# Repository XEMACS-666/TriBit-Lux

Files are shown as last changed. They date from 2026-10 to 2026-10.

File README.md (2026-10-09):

# ☀️ TriBit Lux

### From an LDR experiment to a real hardware PCB.

**TriBit Lux** is a 3-bit flash ADC–style brightness indicator that converts ambient light into a digital level and displays it on a seven-segment display.

The interesting part isn't just the final circuit.

It is the **evolution of the circuit**:

> **What started as Arduino-controlled logic gradually became hardware-controlled logic, then a breadboard prototype, and finally a PCB.**

```text
       LIGHT
         ↓
       LDR
         ↓
    Analog Voltage
         ↓
  LM339 Comparators
         ↓
   Comparator Levels
         ↓
     74F148
  Priority Encoder
         ↓
      3-bit Code
         ↓
      74LS48
  Display Decoder
         ↓
    7-Segment
```

---

## 🧭 The Journey

```text
🧪 V0.0
TinkerCAD + Arduino
     ↓
🌤️ V0.1
Real LDR + Comparators
     ↓
🔌 V1.0
First Breadboard
     ↓
🧠 V1.1
Hardware Priority Encoder
     ↓
🔢 V1.2
Hardware 7-Segment Decoder
     ↓
📟 V1.3
LCD Monitoring
     ↓
🟢 V2.0
KiCad PCB
     ↓
🚧 V2.1
Fabricated Hardware
```

Every version was built to answer a different question.

---

# 🧪 V0.0 — Can the idea work?

### TinkerCAD simulation

The first goal wasn't to make a sophisticated ADC.

It was simply to prove the basic idea:

> **Can a changing analog voltage be converted into a small number of brightness levels and represented digitally?**

Since using a real LDR inside the simulation wasn't the starting point, a **potentiometer** was used to imitate the changing sensor voltage.

The Arduino handled the interpretation and seven-segment display control in software.

### Circuit idea

```text
Potentiometer
     │
     ▼
Comparator Bank
     │
     ▼
Arduino
     │
     ▼
7-Segment Display
```

### 🖼️ Simulation

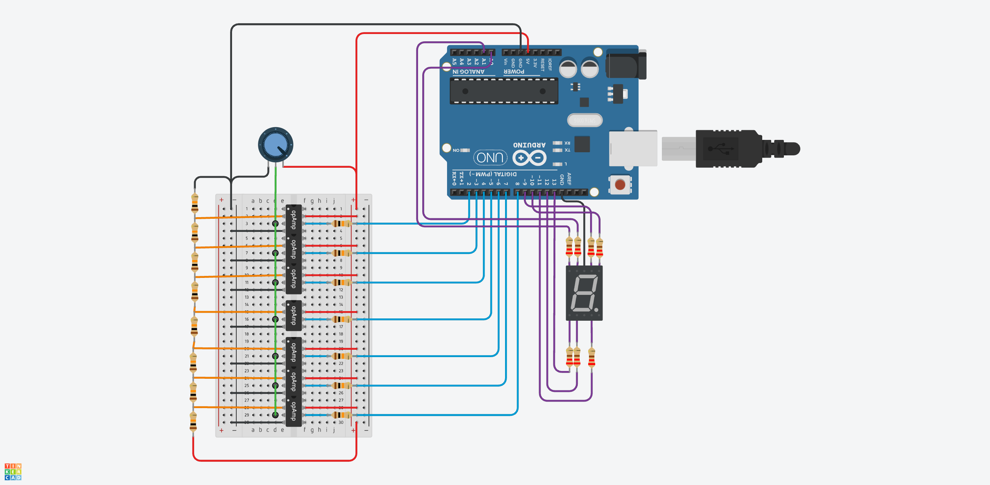
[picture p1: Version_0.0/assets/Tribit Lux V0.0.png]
TriBit Lux V0.0 simulation


**What this version proved:** the overall concept was workable.

**What it didn't prove:** whether the system would behave like a real light sensor.

**So the next question became:**

> What happens when the potentiometer is replaced by actual light?

### 🔗 Files

[TinkerCAD simulation](https://www.tinkercad.com/things/60Tk7pVbgVW-tribit-lux-v00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) · [Schematic](Version_0.0/schematic/Tribit%20Lux%20V0.0.pdf) · [Arduino sketch](Version_0.0/firmware/tribit_lux_v0_00/tribit_lux_v0_00.ino) · [BOM](Version_0.0/bom/bom.csv)

---

# 🌤️ V0.1 — Can real light drive the circuit?

### LDR + LM339

The potentiometer had done its job.

Now it was time to replace the artificial voltage source with the actual thing TriBit Lux was supposed to measure:

**light.**

An **LDR** was introduced together with **LM339 comparators**.

The analog part of the system was now starting to resemble the intended hardware architecture.

```text
            LIGHT
              ↓
             LDR
              ↓
       Voltage Divider
              ↓
       ┌──────────────┐
       │   LM339 × 2  │
       │  Comparators │
       └──────┬───────┘
              ↓
       Digital Levels
              ↓
           Arduino
```

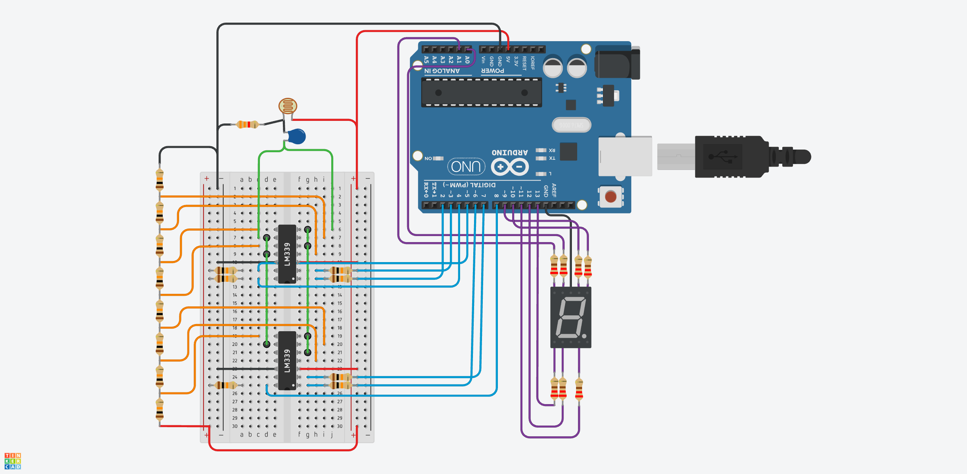
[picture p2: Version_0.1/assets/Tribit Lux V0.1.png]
TriBit Lux V0.1 simulation


The Arduino was still doing the **priority encoding and display logic**, but the important change was that the input was now responding to the real physical quantity of interest.

**Design realization:** the circuit was no longer just a software experiment. The analog front-end itself was becoming real hardware.

### 🔗 Files

[TinkerCAD simulation](https://www.tinkercad.com/things/gNVAR2cQYVG-tribit-lux-v01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) · [Schematic](Version_0.1/schematic/Tribit%20Lux%20V0.1.pdf) · [Arduino sketch](Version_0.1/firmware/tribit_lux_v0_01/tribit_lux_v0_01.ino) · [BOM](Version_0.1/bom/bom.csv)

---

# 🔌 V1.0 — What happens when the simulator becomes a breadboard?

### First physical prototype

At this point, simulation had answered enough questions.

The next step was simple:

> **Build it.**

The LDR and two LM339s were moved onto a physical breadboard, and an **Arduino Nano** was used to read the comparator outputs and control the display.

### ✨ 7-segment pin visualizer

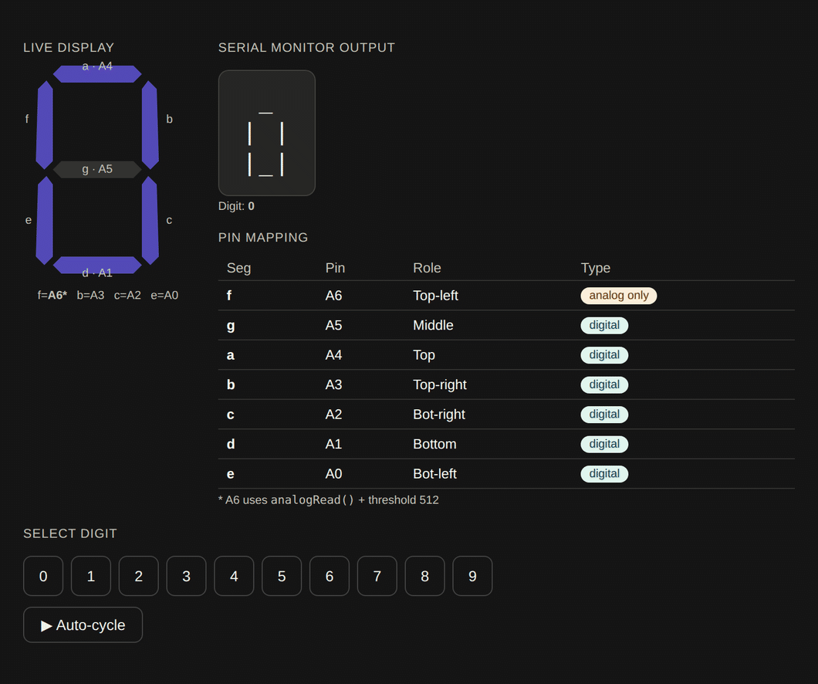
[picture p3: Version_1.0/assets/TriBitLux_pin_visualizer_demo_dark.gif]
Animated TriBit Lux 7-segment pin visualizer


*An animated guide to the seven-segment display pin layout. The breadboard recording is a video, so use the link below to open it.*

The important lesson here was that simulation and physical electronics are not quite the same thing.

Now the project had to deal with:

- actual component tolerances
- real wiring
- power connections
- sensor behaviour
- breadboard parasitics
- physical display pin arrangements

The Arduino still performed most of the digital decision-making.

That raised the next engineering question:

> **Why should a microcontroller perform a job that a digital logic IC can perform directly?**

### 🔗 Files

[▶️ Watch the breadboard video](Version_1.0/assets/TriBitLux_V1_0%202026-10-06%20at%2023.10.18.mp4) · [Open the interactive 7-segment pin visualizer](https://xemacs-666.github.io/TriBit-Lux/Version_1.0/assets/TriBitLux_V1_0_pin_visualizer.html) · [Serial visualizer sketch](Version_1.0/firmware/TriBitLux_V1_0_visualizer/TriBitLux_V1_0_visualizer.ino)

> The visualizer sketch is a learning/debugging aid, not the complete V1.0 firmware.

---

# 🧠 V1.1 — Can the hardware make the decision?

### Introducing the 74F148

This was the first major step toward the original hardware-design idea.

Instead of asking the Arduino:

> "Which comparator is active?"

the circuit now contains a dedicated **74F148 priority encoder**.

```text
LM339 Comparator Bank
         │
         ▼
    Thermometer
       Code
         │
         ▼
      74F148
  Priority Encoder
         │
         ▼
      3-bit
      Output
         │
         ▼
      Arduino
```

### 🖼️ Prototype and layout

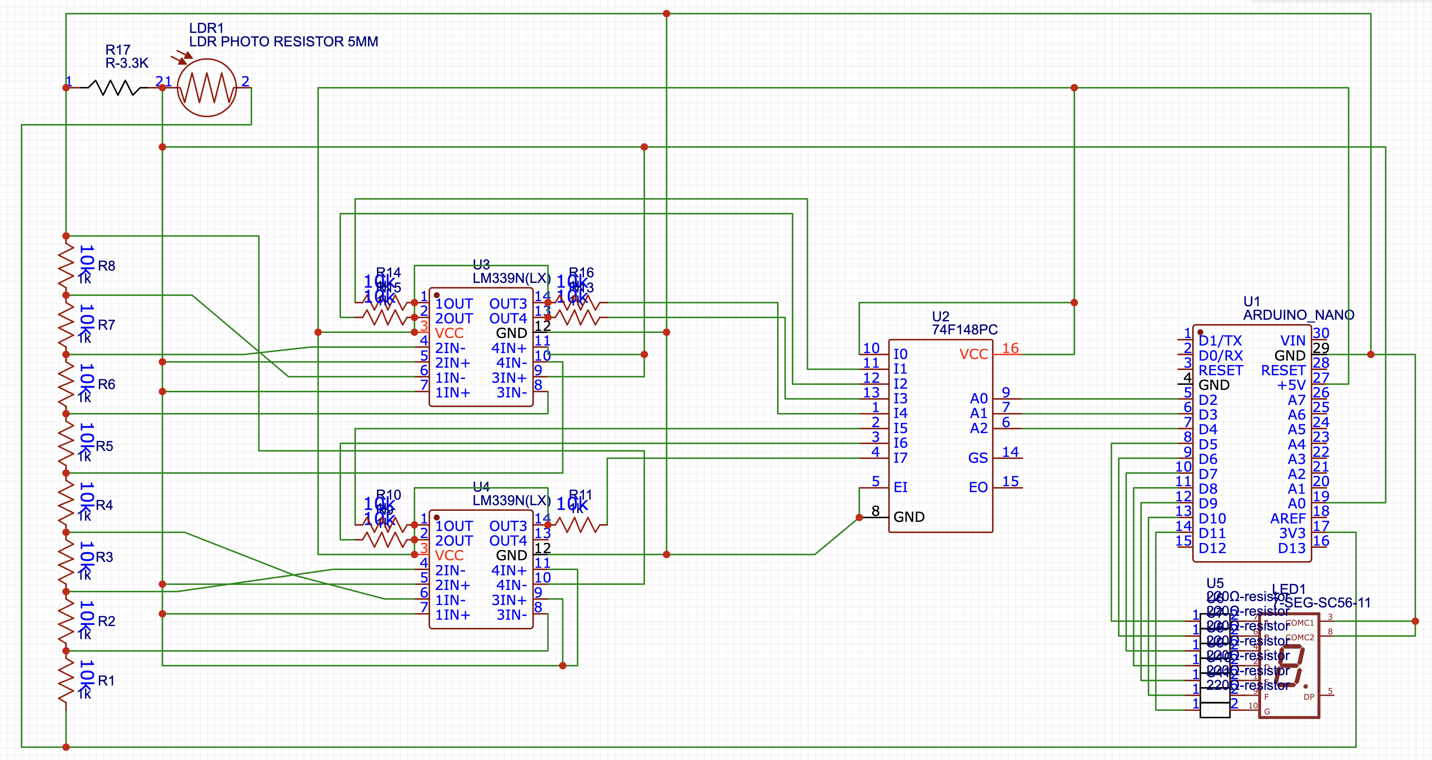
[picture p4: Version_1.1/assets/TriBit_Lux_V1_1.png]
V1.1 schematic


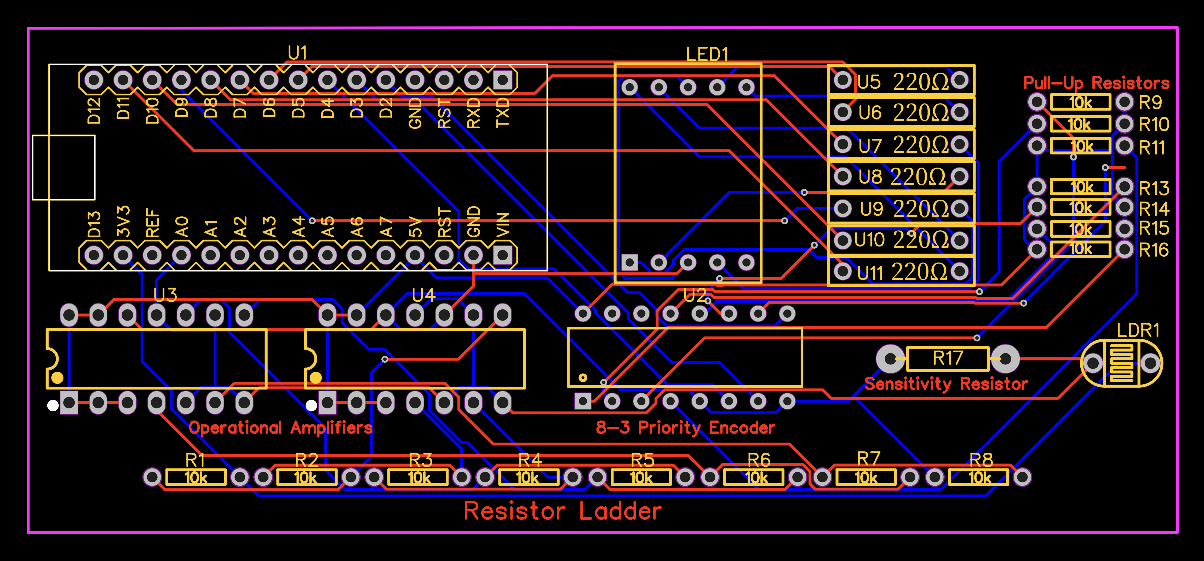
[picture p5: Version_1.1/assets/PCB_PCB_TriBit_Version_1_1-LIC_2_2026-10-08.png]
V1.1 PCB layout


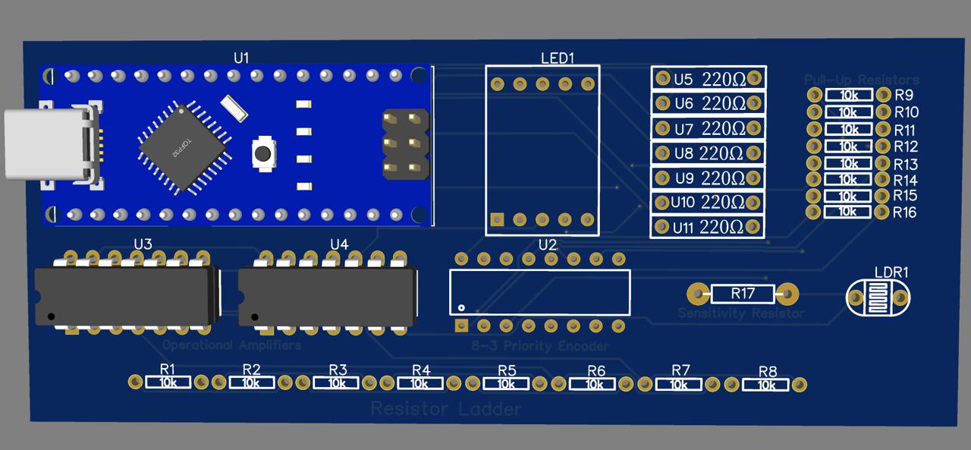
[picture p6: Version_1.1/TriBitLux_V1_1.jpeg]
V1.1 prototype


### Why this mattered

The Arduino wasn't removed.

Instead, its role was deliberately reduced.

The goal was to understand the boundary between **analog hardware, digital logic and software**.

The 74F148 now handled the priority encoding, while the Nano simply observed the result.

This version marked the transition from:

**"Arduino reads the circuit"**

to

**"The circuit itself produces a meaningful digital result."**

### 🔗 Files

[Schematic](Version_1.1/schematic/) · [PCB](Version_1.1/pcb/) · [BOM](Version_1.1/bom/) · [Gerbers](Version_1.1/gerbers/)

---

# 🔢 V1.2 — Can the display become hardware too?

### Introducing the 74LS48

The next dependency on the Arduino was even more obvious.

The encoder already produced a digital code.

So why should the Nano turn that code into seven-segment signals?

It shouldn't.

The **74LS48** was added to perform the display decoding directly in hardware.

```text
LM339
 │
 ▼
74F148
 │
 │ 3-bit code
 ▼
74LS48
 │
 ▼
7-Segment
```

### Physical build

| Prototype view 1 | Prototype view 2 | Prototype view 3 |
|:---:|:---:|:---:|
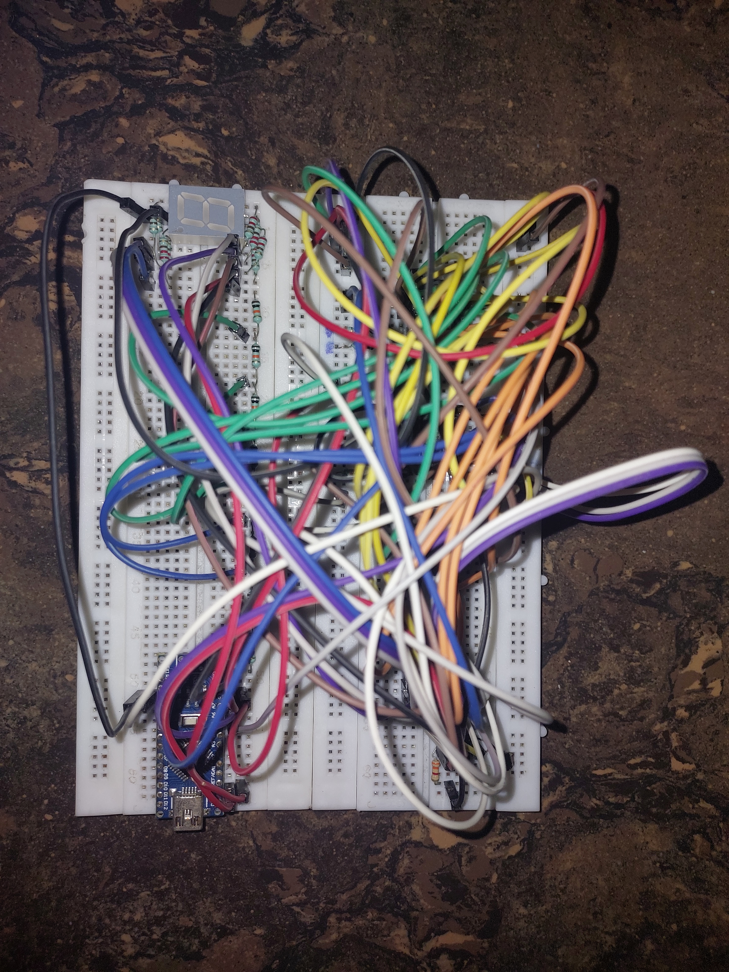
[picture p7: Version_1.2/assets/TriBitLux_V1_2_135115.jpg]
V1.2 prototype view 1
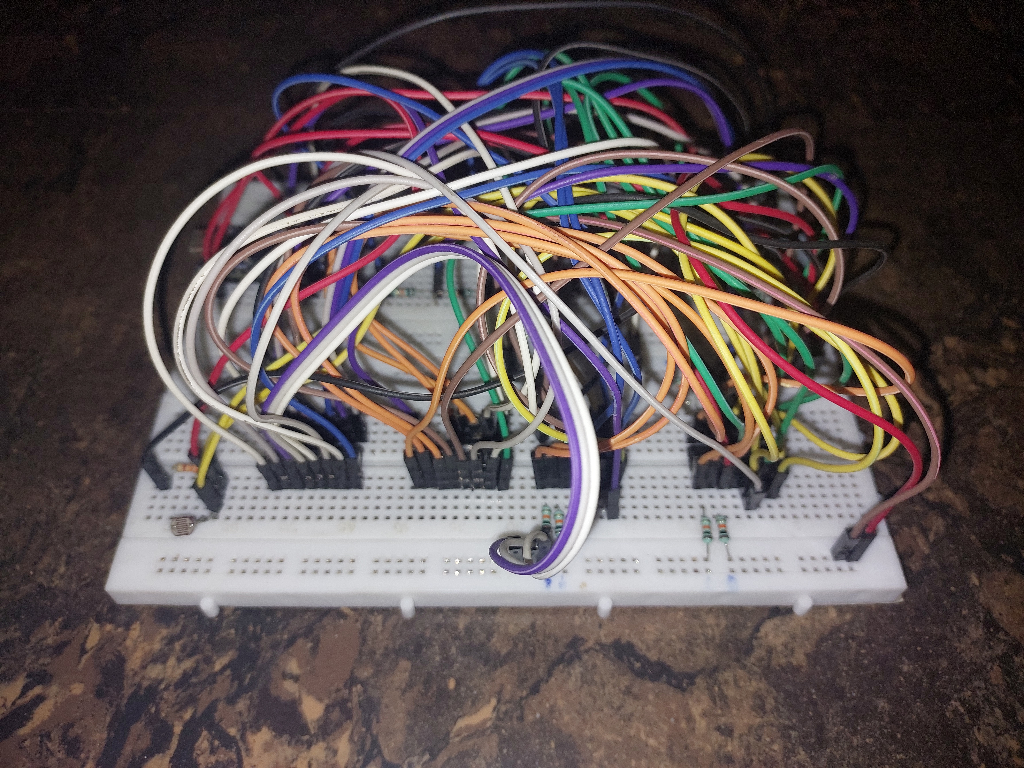
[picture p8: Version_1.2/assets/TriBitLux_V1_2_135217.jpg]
V1.2 prototype view 2
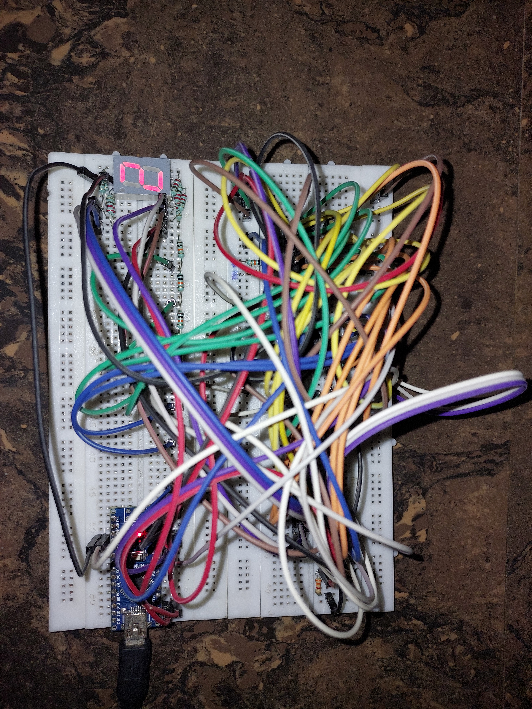
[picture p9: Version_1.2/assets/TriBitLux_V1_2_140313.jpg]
V1.2 prototype view 3
|  |  |  |

Now the complete display path was handled by dedicated hardware.

The Arduino's job became much smaller:

> **Observe the binary output and print it to the serial monitor for verification.**

This was an important milestone because the seven-segment display was now **physically driven by logic ICs rather than Arduino display code**.

### 🔗 Files

[Nano serial-monitor sketch](Version_1.2/firmware/TriBitLux_V1_2_LIC/TriBitLux_V1_2_LIC.ino) · [Video](Version_1.2/assets/)

> The sketch also contains seven-segment output code for experimentation, but that is **not** the display path used in the photographed V1.2 build.

---

# 📟 V1.3 — What if the circuit could tell us more?

### Adding an LCD

The seven-segment display tells us the **level**.

But during development, another question became useful:

> **What is the sensor voltage actually doing?**

So a **16×2 I²C LCD** was added.

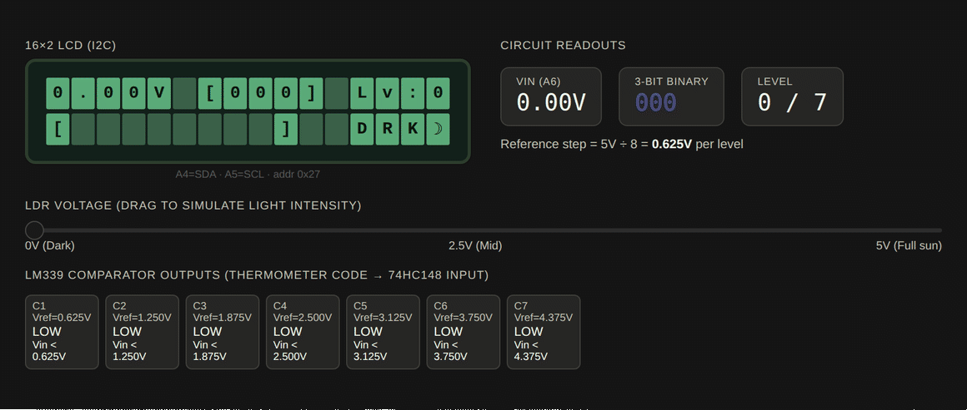
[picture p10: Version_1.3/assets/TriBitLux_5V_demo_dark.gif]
Animated V1.3 light-level demonstration


*Animated 5 V demonstration of the TriBit Lux indicator.*

### 🖼️ Prototype gallery

| Prototype view 1 | Prototype view 2 |
|:---:|:---:|
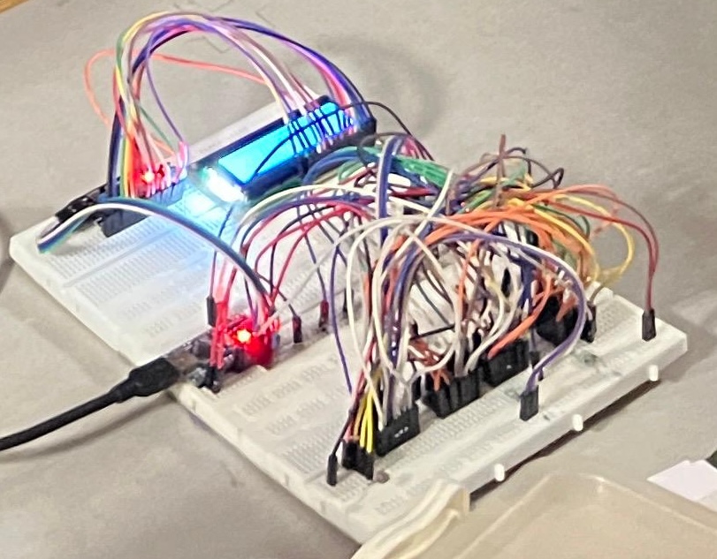
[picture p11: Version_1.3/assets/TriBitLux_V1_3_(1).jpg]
V1.3 prototype with LCD, view 1
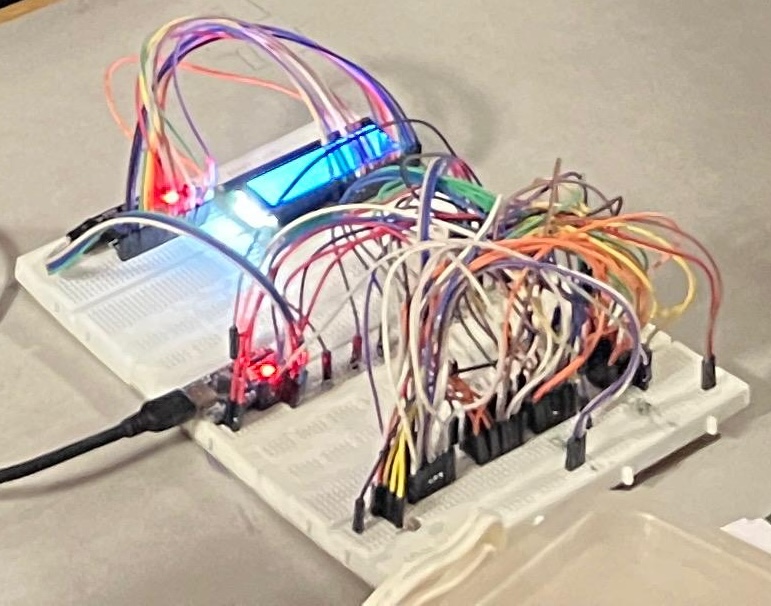
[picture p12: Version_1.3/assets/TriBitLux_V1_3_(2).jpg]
V1.3 prototype with LCD, view 2
|  |  |

This version wasn't intended to replace the hardware logic.

Instead, it became a **development and monitoring stage**.

The Nano reads the LDR voltage through its analog input and calculates the displayed level in software.

```text
            LDR
             │
             ├──────────► LM339 → 74F148 → 74LS48 → 7-Segment
             │
             ▼
         Arduino ADC
             │
             ▼
            LCD
```

This is important because **V1.3's LCD firmware does not read the 74F148 outputs**.

It independently measures the LDR voltage and calculates the level.

That made the LCD useful for understanding what was happening inside the analog section while the hardware seven-segment path continued doing its own job.

### 🔗 Files

[Photo 1](Version_1.3/assets/TriBitLux_V1_3%20%281%29.jpg) · [Photo 2](Version_1.3/assets/TriBitLux_V1_3%20%282%29.jpg) · [Open the 5 V LCD visualization](https://xemacs-666.github.io/TriBit-Lux/Version_1.3/assets/TriBitLux_V1_3_%285V%29.html) · [LCD sketch](Version_1.3/firmware/TriBitLux_V1_3/TriBitLux_V1_3.ino)

---

# 🟢 V2.0 — Can the whole thing become a proper board?

### From jumper wires to copper traces.

By now the architecture had been tested through multiple physical iterations.

The next problem was no longer:

> "Does the circuit work?"

It was:

> **"Can I package the circuit into something compact, repeatable and manufacturable?"**

That became **V2.0**.

The circuit was recreated in **KiCad** as an editable schematic and PCB layout.

### 🖼️ V2.0 design gallery

| Schematic | PCB layout |
|:---:|:---:|
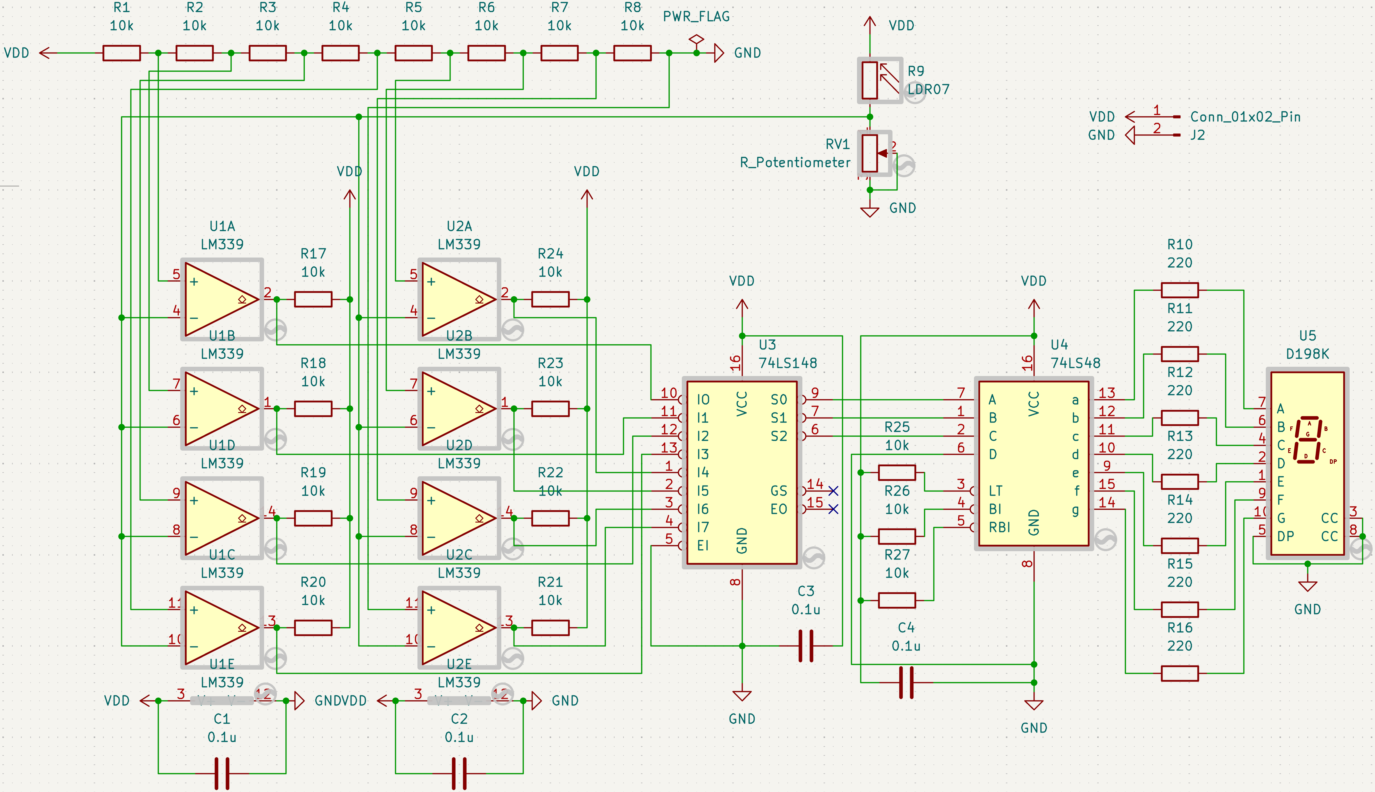
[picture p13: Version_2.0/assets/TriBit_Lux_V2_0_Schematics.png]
V2.0 schematic
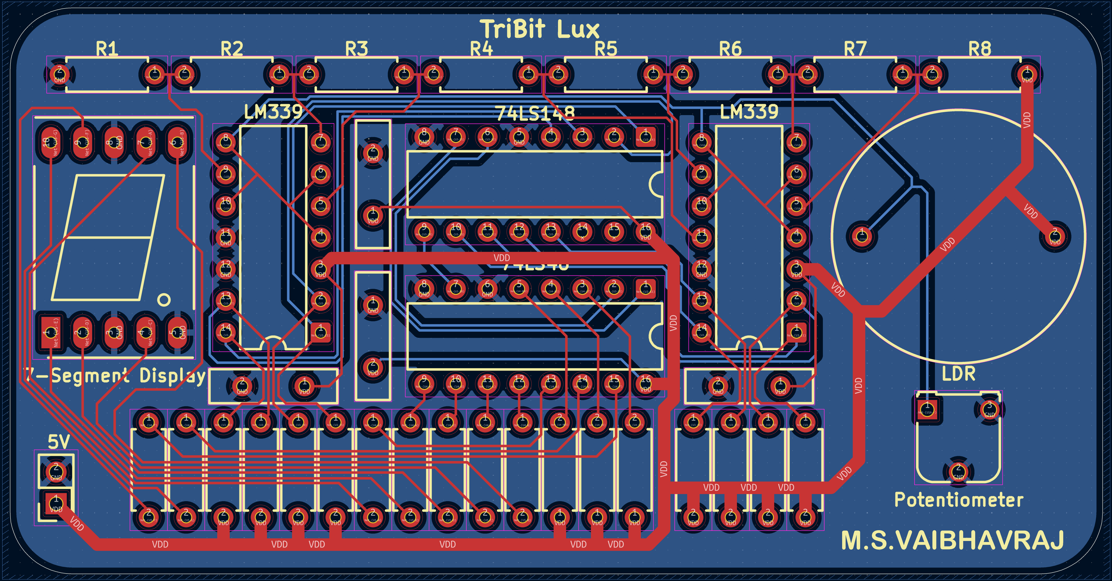
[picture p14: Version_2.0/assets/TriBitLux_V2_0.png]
V2.0 PCB layout
|  |  |

| PCB top view | PCB bottom view |
|:---:|:---:|
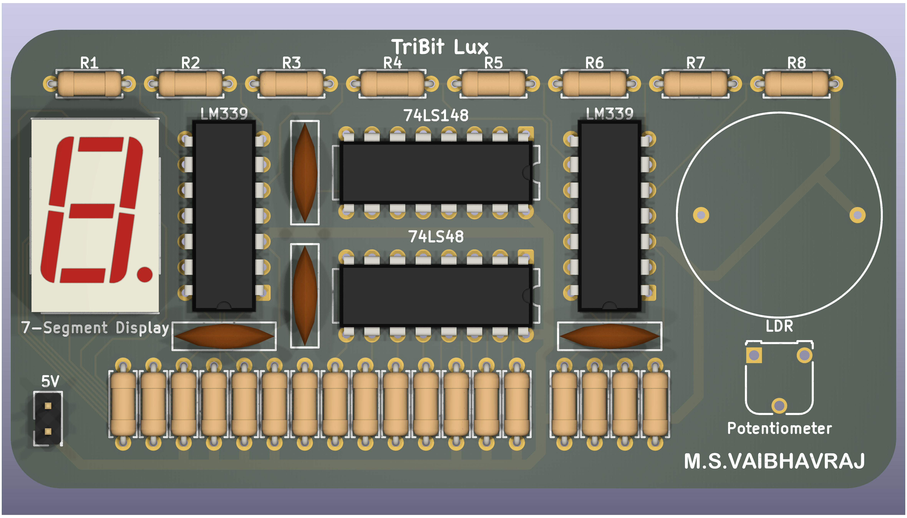
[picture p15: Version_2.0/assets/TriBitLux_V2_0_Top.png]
V2.0 PCB top view
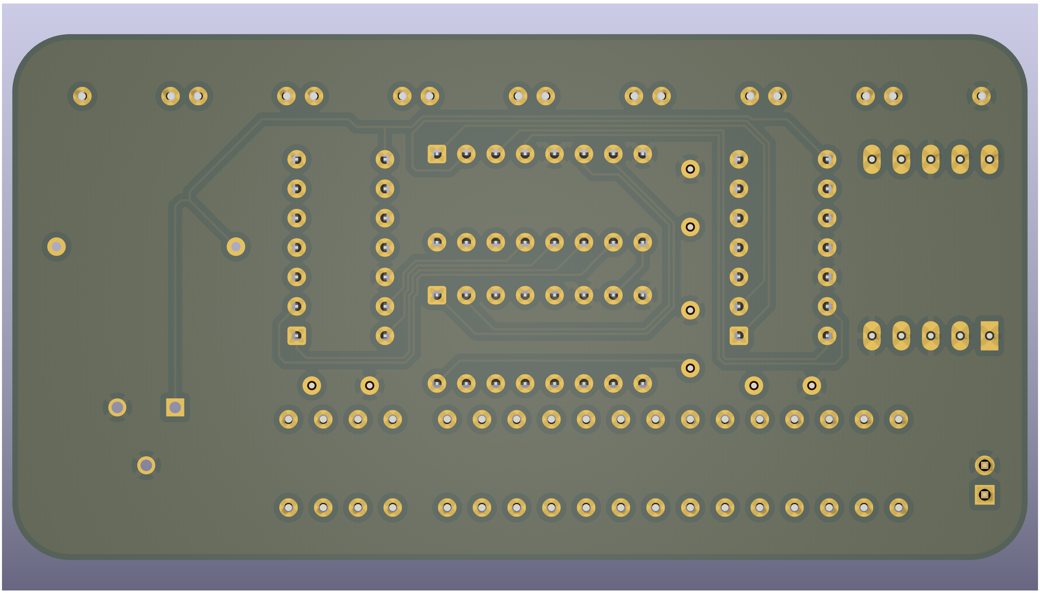
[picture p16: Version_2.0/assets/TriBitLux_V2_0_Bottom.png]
V2.0 PCB bottom view
|  |  |

### What changed?

**☀️ 20 mm LDR opening**

The sensor opening was enlarged to make physical placement and light exposure more practical.

**🎚️ Adjustable sensitivity**

A potentiometer was introduced so the response of the brightness indicator can be adjusted rather than being completely fixed.

**🛡️ 0.1 µF decoupling**

Local bypass capacitors were added around the IC supply rails to improve supply stability and reduce unwanted noise.

**🧱 Through-hole construction**

The board remains intentionally friendly to manual assembly, inspection and modification.

---

# 🧩 V2.0 Hardware Architecture

```text
                      ☀️ LIGHT
                         │
                         ▼
                   ┌───────────┐
                   │    LDR    │
                   └─────┬─────┘
                         │
                   Sensor Voltage
                         │
                         ▼
              ┌────────────────────┐
              │      LM339 × 2     │
              │  Comparator Bank   │
              └─────────┬──────────┘
                        │
                  7 comparator
                    decisions
                        │
                        ▼
                ┌──────────────┐
                │    74F148    │
                │   Priority   │
                │    Encoder   │
                └───────┬──────┘
                        │
                      3 bits
                   ┌────┴────┐
                   ▼         ▼
              Debug/Test   74LS48
                              │
                              ▼
                          7-Segment
                           Display
```

The important architectural change is that the **core signal path no longer depends on the Arduino**.

---

# 🏗️ Inside V2.0

The editable KiCad project is kept here:

```text
Version_2.0/
└── TriBitLux_V2_0/
    ├── TriBitLux_V2_0.kicad_pro
    ├── TriBitLux_V2_0.kicad_sch
    └── TriBitLux_V2_0.kicad_pcb
```

Only the actual KiCad design files are tracked.

KiCad-generated temporary files such as:

```text
fp-info-cache
*.kicad_prl
*.kicad_sch-bak
*-backups/
```

are intentionally excluded from version control.

Manufacturing outputs are kept separately:

```text
Version_2.0/
├── gerber/
│   └── gerber.zip
├── bom/
├── cpl/
├── schematic/
└── TriBitLux_V2_0/
    ├── TriBitLux_V2_0.kicad_pro
    ├── TriBitLux_V2_0.kicad_sch
    └── TriBitLux_V2_0.kicad_pcb
```

### Current status

**PCB design complete. Fabrication pending.**

```text
Schematic
   ✅
    ↓
PCB Layout
   ✅
    ↓
Gerber Generation
   ✅
    ↓
Manufacturing
   ⏳
    ↓
Assembly
   ⏳
    ↓
Power-up
   ⏳
    ↓
Real-world validation
   ⏳
```

---

# 📈 The Engineering Progression

The versions are not just revisions of the same circuit.

Each one removed uncertainty.

| Version | Question being answered |
|:---:|---|
| **V0.0** | Can the basic concept work? |
| **V0.1** | Can actual light be converted into useful comparator states? |
| **V1.0** | Does the circuit survive physical implementation? |
| **V1.1** | Can priority encoding be moved into hardware? |
| **V1.2** | Can display decoding also be moved into hardware? |
| **V1.3** | Can additional measurements help understand the circuit? |
| **V2.0** | Can the validated circuit be packaged into a PCB? |
| **V2.1** | Will the manufactured PCB actually work? |

---

# 🚧 V2.1 — The Board Meets Reality

The next version won't begin in KiCad.

It will begin with a box containing a fabricated PCB.

### Planned validation

```text
PCB Arrival
   ↓
Visual Inspection
   ↓
Continuity Check
   ↓
5 V Rail Check
   ↓
IC Power Verification
   ↓
Comparator Threshold Test
   ↓
74F148 Verification
   ↓
74LS48 + Display Test
   ↓
LDR Response
   ↓
Sensitivity Adjustment
   ↓
Full Brightness Test
```

The first successful power-up will be a different kind of milestone from everything before it.

Until then:

> **V2.0 is a design.  
> V2.1 will prove whether the design was right.**

---

# 📂 Repository Structure

```text
TriBit Lux/
│
├── README.md
├── .gitignore
│
├── Version_0.0/
│   ├── assets/
│   │   └── Tribit Lux V0.0.png
│   ├── bom/
│   │   └── bom.csv
│   ├── firmware/
│   │   └── tribit_lux_v0_00/
│   │       └── tribit_lux_v0_00.ino
│   └── schematic/
│       └── Tribit Lux V0.0.pdf
│
├── Version_0.1/
│   ├── assets/
│   │   └── Tribit Lux V0.1.png
│   ├── bom/
│   │   └── bom.csv
│   ├── firmware/
│   │   └── tribit_lux_v0_01/
│   │       └── tribit_lux_v0_01.ino
│   └── schematic/
│       └── Tribit Lux V0.1.pdf
│
├── Version_1.0/
│   ├── assets/
│   │   ├── TriBitLux_V1_0_pin_visualizer_demo_dark.gif
│   │   ├── TriBitLux_V1_0 2026-10-06 at 23.10.18.mp4
│   │   └── TriBitLux_V1_0_pin_visualizer.html
│   └── firmware/
│       └── TriBitLux_V1_0_visualizer/
│           └── TriBitLux_V1_0_visualizer.ino
│
├── Version_1.1/
│   ├── assets/
│   ├── bom/
│   ├── firmware/
│   │   └── TriBitLux_V1_1_LIC/
│   │       └──TriBitLux_V1_1_LIC.ino
│   ├── gerbers/
│   ├── pcb/
│   └── schematic/
│
├── Version_1.2/
│   ├── assets/
│   └── firmware/
│       └── TriBitLux_V1_2_LIC/
│           └── TriBitLux_V1_2_LIC.ino
│
├── Version_1.3/
│   ├── assets/
│   └── firmware/
│       └── TriBitLux_V1_3/
│           └── TriBitLux_V1_3.ino
│
└── Version_2.0/
    ├── assets/
    ├── bom/
    ├── cpl/
    ├── gerber/
    │   └── gerber.zip
    ├── schematic/
    └── TriBitLux_V2_0/
        ├── TriBitLux_V2_0.kicad_pro
        ├── TriBitLux_V2_0.kicad_sch
        └── TriBitLux_V2_0.kicad_pcb
```

---

# ⚠️ Notes

Some older KiCad backup files previously contained **`PhotoDiode`** in their filenames.

That naming is legacy.

The actual sensor used throughout TriBit Lux is an **LDR (photoresistor)**.

The HTML, GIF, video and other media are supporting visualization, documentation and learning/debugging material.

The **editable KiCad schematic and PCB are the authoritative design sources for V2.0**.

---

# ☀️ TriBit Lux

### One light. Eight levels. Three bits.

```text
      🌑
       │
      LDR
       │
       ▼
 COMPARATOR BANK
       │
       ▼
    74F148
       │
       ▼
     3 BITS
       │
       ▼
    74LS48
       │
       ▼
   7-SEGMENT
       │
       ▼
      0–7
```

**V0.0 → V0.1 → V1.0 → V1.1 → V1.2 → V1.3 → V2.0 → 🚧 V2.1**

> **From a simulated idea to a board that has to work in the real world.**

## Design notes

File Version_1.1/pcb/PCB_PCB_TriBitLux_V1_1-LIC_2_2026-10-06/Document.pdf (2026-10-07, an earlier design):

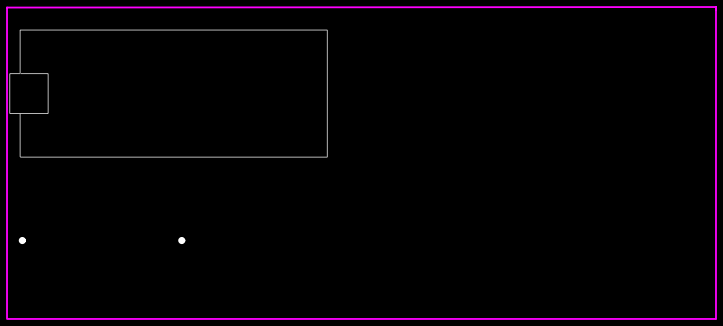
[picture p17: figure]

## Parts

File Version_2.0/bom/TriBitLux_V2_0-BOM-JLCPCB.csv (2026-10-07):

Comment | Designator | Footprint | JLCPCB Part #
Conn_01x02_Pin | J2 | Connector_PinHeader_2.54mm:PinHeader_2x01_P2.54mm_Vertical | C557685
R_Potentiometer | RV1 | Potentiometer_THT:Potentiometer_Runtron_RM-065_Vertical | C5205021
74LS48 | U4 | Package_DIP:DIP-16_W7.62mm | C22466304
LM339 | U1,U2 | Package_DIP:DIP-14_W7.62mm | C725324
220 | R10,R11,R12,R13,R14,R15,R16 | Resistor_THT:R_Axial_DIN0207_L6.3mm_D2.5mm_P7.62mm_Horizontal | C57439
10k | R1,R2,R3,R4,R5,R6,R7,R8,R17,R18,R19,R20,R21,R22,R23,R24,R25,R26,R27 | Resistor_THT:R_Axial_DIN0207_L6.3mm_D2.5mm_P7.62mm_Horizontal | C57436
0.1u | C1,C2,C3,C4 | Capacitor_THT:C_Disc_D10.0mm_W2.5mm_P5.00mm | C254085
D198K | U5 | Display_7Segment:7SegmentLED_LTS6760_LTS6780 | C8093
LDR07 | R9 | OptoDevice:R_LDR_D20mm_P17.5mm_Vertical | C779581
74LS148 | U3 | Package_DIP:DIP-16_W7.62mm | C22384760

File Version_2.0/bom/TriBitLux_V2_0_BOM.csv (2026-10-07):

JLCPCB BOM Tool - BOM Matching
BOM name?PhotoDiode-JLCPCB Assembly Order.xlsx |  |  |  | Download Time?2026-10-05 01:59:07 |  |  |  | * Our matching results are updated in real-time, but stock and prices may change. If it's been over 24 hours, please re-match before placing your order.
PCB Assembled Qty?2 |  |  |  | Est. Total Price?9.3674 (Pre-order parts require a quotation for final pricing.)
Your BOM |  |  |  | Matched Parts |  |  |  |  |  |  | Order Information
Designator | Comment | Footprint | JLCPCB Part # | Matches | Part # | Manufacturer | Footprint | Description | Category | Warning | JLCPCB Part # | Product link | Source | Lib Type | MOQ | Availability | My Parts(JLCPCB Parts) | My Parts(Global sourcing & consigned parts) | Rec. Order Qty | Unit Price ($) | Total Price ($)
J2 | Conn_01x02_Pin | Connector_PinHeader_2.54mm:PinHeader_2x01_P2.54mm_Vertical |  | Select by System | XY308-2.54-2P | Ningbo Xinlaiya Elec. | Connector_PinHeader_2.54mm:PinHeader_2x01_P2.54mm_Vertical | 1 1 150V 18~26 1x2P 2 2.54mm 2P 6A Green M1.6 Through Hole ??,P=2.54mm Screw Terminal Blocks ROHS | Screw Terminal Blocks |  | C557685 | https://jlcpcb.com/partdetail/Ningbo_Xinlaiya_Elec-XY308_2_542P/C557685 | In-stock | Extended | 1 | 6205 | 0 | 0 | 2 | 0.2465 | 0.493
RV1 | R_Potentiometer | Potentiometer_THT:Potentiometer_Runtron_RM-065_Vertical |  | Select by System | RM065-103(10K) | BOCHEN(Chengdu Guosheng Tech) | Potentiometer_THT:Potentiometer_Runtron_RM-065_Vertical | 100mW 10k? 50V ±25% ??,7.3x6.4mm Potentiometers, Variable Resistors ROHS | Potentiometers, Variable Resistors |  | C5205021 | https://jlcpcb.com/partdetail/5896379-RM065_103_10K/C5205021 | In-stock | Extended | 1 | 13934 | 0 | 0 | 2 | 0.0608 | 0.1216
U4 | 74LS48 | Package_DIP:DIP-16_W7.62mm |  | Select by System | SN74LS48N(LX) | lingxingic | Package_DIP:DIP-16_W7.62mm | -40?~+125? 13mA 2V~6V 500mW 7 Segment x 1 Digit Lamp test function?Leading zero blanking?Trailing zero blanking DIP-16 Digital Tube Drivers ROHS | Digital Tube Drivers |  | C22466304 | https://jlcpcb.com/partdetail/lingxingic-SN74LS48N_LX/C22466304 | In-stock | Extended | 1 | 10 | 0 | 0 | 2 | 0.3983 | 0.7966
U1,U2 | LM339 | Package_DIP:DIP-14_W7.62mm |  | Select by System | LM339N | HGSEMI | Package_DIP:DIP-14_W7.62mm | -16V~-1.5V?1.5V~16V 0?~+70? 1.3us 25nA 2mV 36V 3V~32V 5nA 800uA Four channels TTL?CMOS DIP-14 Comparators ROHS | Comparators |  | C725324 | https://jlcpcb.com/partdetail/HGSEMI-LM339N/C725324 | In-stock | Extended | 1 | 3702 | 0 | 0 | 4 | 0.1332 | 0.5328
R10,R11,R12,R13,R14,R15,R16 | 220 | Resistor_THT:R_Axial_DIN0207_L6.3mm_D2.5mm_P7.62mm_Horizontal |  | Select by System | MFR0W4F2200A50 | UNI-ROYAL(Uniroyal Elec) | Resistor_THT:R_Axial_DIN0207_L6.3mm_D2.5mm_P7.62mm_Horizontal | 220? 250V 250mW Metal Film Resistor ±1% ±50ppm/? ??,D2.2xL6.5mm Through Hole Resistors ROHS | Through Hole Resistors |  | C57439 | https://jlcpcb.com/partdetail/58473-MFR0W4F2200A50/C57439 | In-stock | Extended | 1 | 13419 | 0 | 0 | 14 | 0.0121 | 0.1694
R1,R2,R3,R4,R5,R6,R7,R8,R17,R18,R19,R20,R21,R22,R23,R24,R25,R26,R27 | 10k | Resistor_THT:R_Axial_DIN0207_L6.3mm_D2.5mm_P7.62mm_Horizontal |  | Select by System | MFR0W4F1002A50 | UNI-ROYAL(Uniroyal Elec) | Resistor_THT:R_Axial_DIN0207_L6.3mm_D2.5mm_P7.62mm_Horizontal | 10k? 250V 250mW Metal Film Resistor ±1% ±50ppm/? ??,D2.2xL6.5mm Through Hole Resistors ROHS | Through Hole Resistors |  | C57436 | https://jlcpcb.com/partdetail/58470-MFR0W4F1002A50/C57436 | In-stock | Extended | 1 | 150466 | 0 | 0 | 38 | 0.0141 | 0.5358
C1,C2,C3,C4 | 0.1u | Capacitor_THT:C_Disc_D10.0mm_W2.5mm_P5.00mm |  | Select by System | CC1H104MC1FD3F6C10MF | Dersonic | Capacitor_THT:C_Disc_D10.0mm_W2.5mm_P5.00mm | 100nF 2.2mm 5.08mm 50V 6mm Y5V ±20% Plugin,P=5.08mm Through Hole Ceramic Capacitors ROHS | Through Hole Ceramic Capacitors |  | C254085 | https://jlcpcb.com/partdetail/Dersonic-CC1H104MC1FD3F6C10MF/C254085 | In-stock | Extended | 1 | 339833 | 0 | 0 | 8 | 0.0259 | 0.2072
U5 | D198K | Display_7Segment:7SegmentLED_LTS6760_LTS6780 |  | Unconfirmed | FJ5161AH | Shenzhen Zhihao Elec | Display_7Segment:7SegmentLED_LTS6760_LTS6780 | -40?~+85? 0.56 1 12.6mm 19mm 25mcd 2V 7 Segment 8mm Common Cathode Red ?? LED Segment Displays ROHS | LED Segment Displays | 1.The comment (FJ5161AH) of this part does not match the one (D198K) provided in your BOM. Please confirm; | C8093 | https://jlcpcb.com/partdetail/Shenzhen_ZhihaoElec-FJ5161AH/C8093 | In-stock | Extended | 1 | 10574 | 0 | 0 | 2 | 0.2171 | 0.4342
R9 | LDR07 | OptoDevice:R_LDR_D20mm_P17.5mm_Vertical |  | Select by System | GL20528 | JCHL(Shenzhen Jing Chuang He Li Tech) | OptoDevice:R_LDR_D20mm_P17.5mm_Vertical | -30?~+70? 0.6 10k?~20k? 2M? 30ms 30ms 500V 560nm ??,P=15.5mm Photoresistors ROHS | Photoresistors |  | C779581 | https://jlcpcb.com/partdetail/830709-GL20528/C779581 | In-stock | Extended | 1 | 8 | 0 | 0 | 2 | 1.0957 | 2.1914
U3 | 74LS148 | Package_DIP:DIP-16_W7.62mm |  | Select by System | SN74LS148N(LX) | lingxingic | Package_DIP:DIP-16_W7.62mm | -40?~+125? 14ns@6V,50pF 2V~6V 2uA 5.2mA 5.2mA 74LS 8/3 Decoder Single Supply DIP-16 Signal Switches, Multiplexers, Decoders ROHS | Signal Switches, Multiplexers, Decoders |  | C22384760 | https://jlcpcb.com/partdetail/lingxingic-SN74LS148N_LX/C22384760 | In-stock | Extended | 1 | 80 | 0 | 0 | 2 | 0.3206 | 0.6412

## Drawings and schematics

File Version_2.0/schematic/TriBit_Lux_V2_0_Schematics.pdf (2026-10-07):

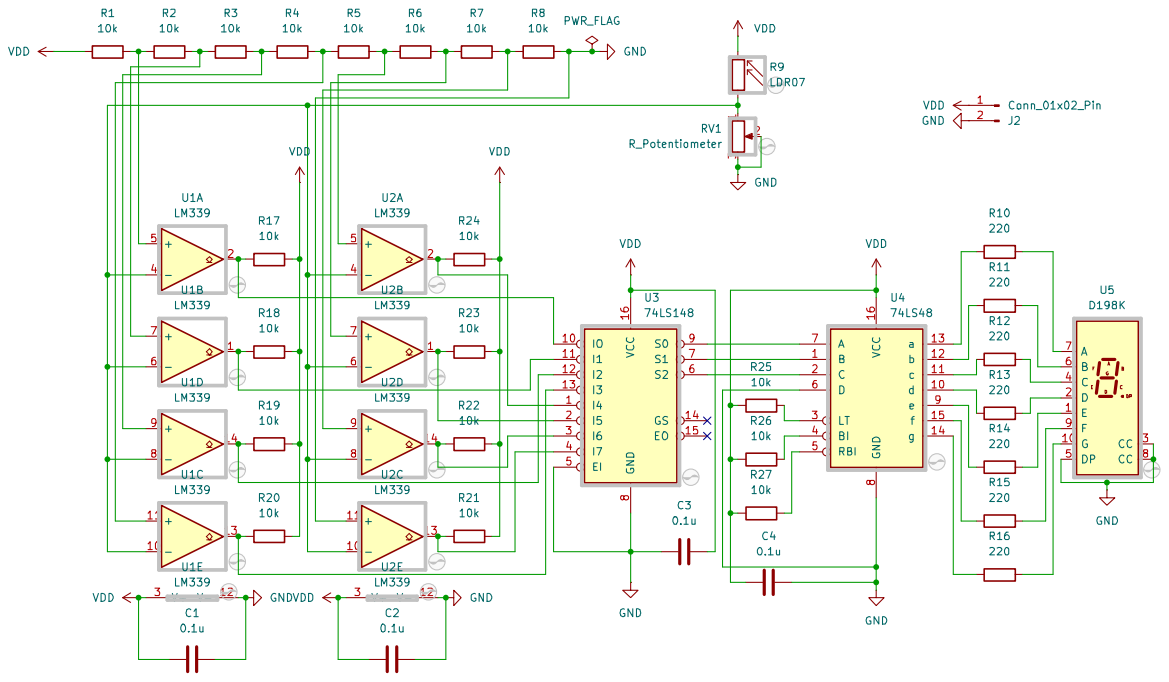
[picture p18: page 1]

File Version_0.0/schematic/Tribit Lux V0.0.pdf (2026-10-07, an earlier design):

A

1 | 2 | 3 | 4 | 5 | 6

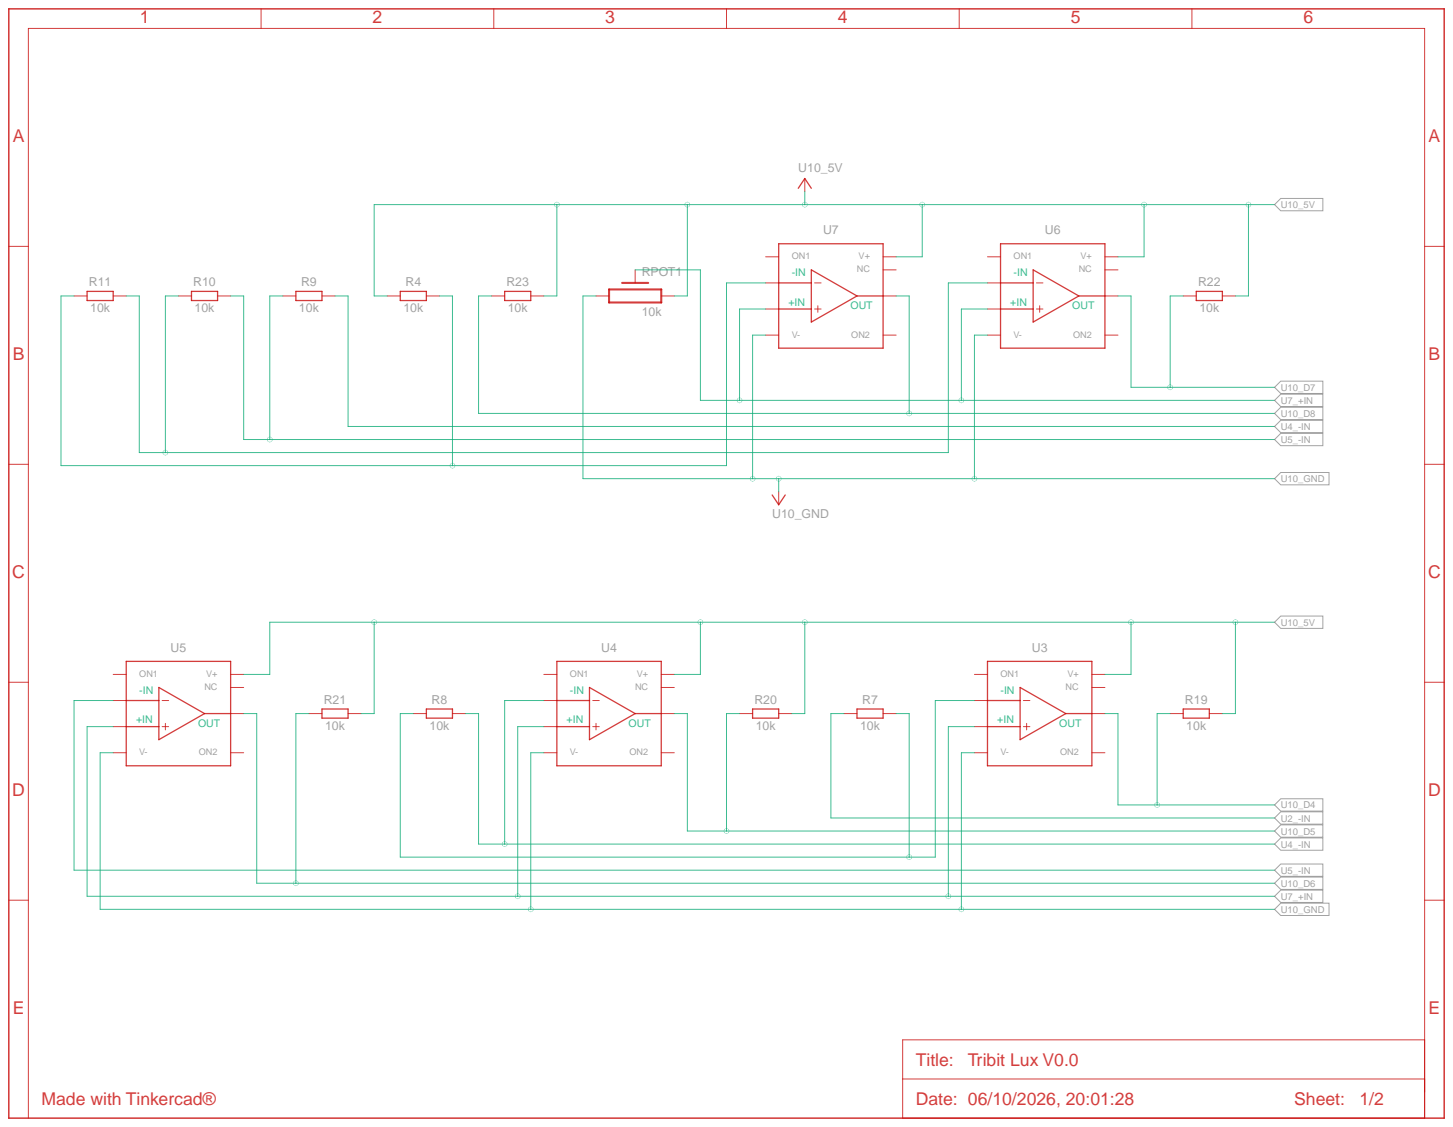
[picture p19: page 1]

A

1 | 2 | 3 | 4 | 5 | 6

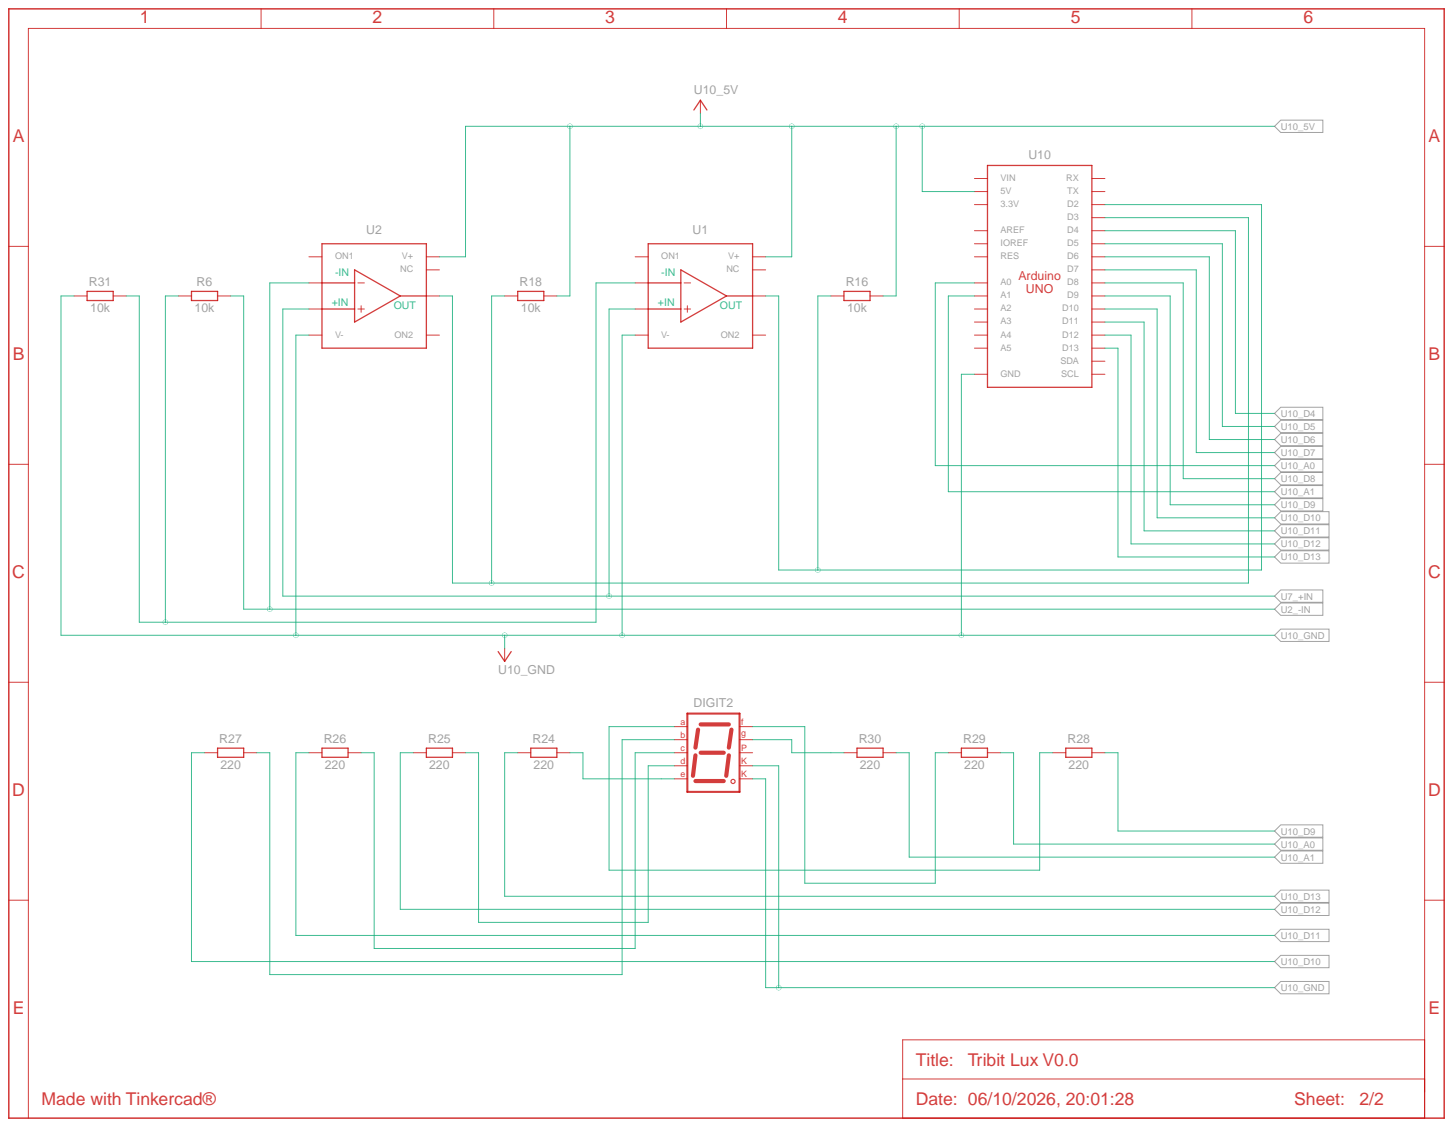
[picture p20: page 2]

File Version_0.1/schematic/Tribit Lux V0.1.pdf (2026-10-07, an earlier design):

A

1 | 2 | 3 | 4 | 5 | 6

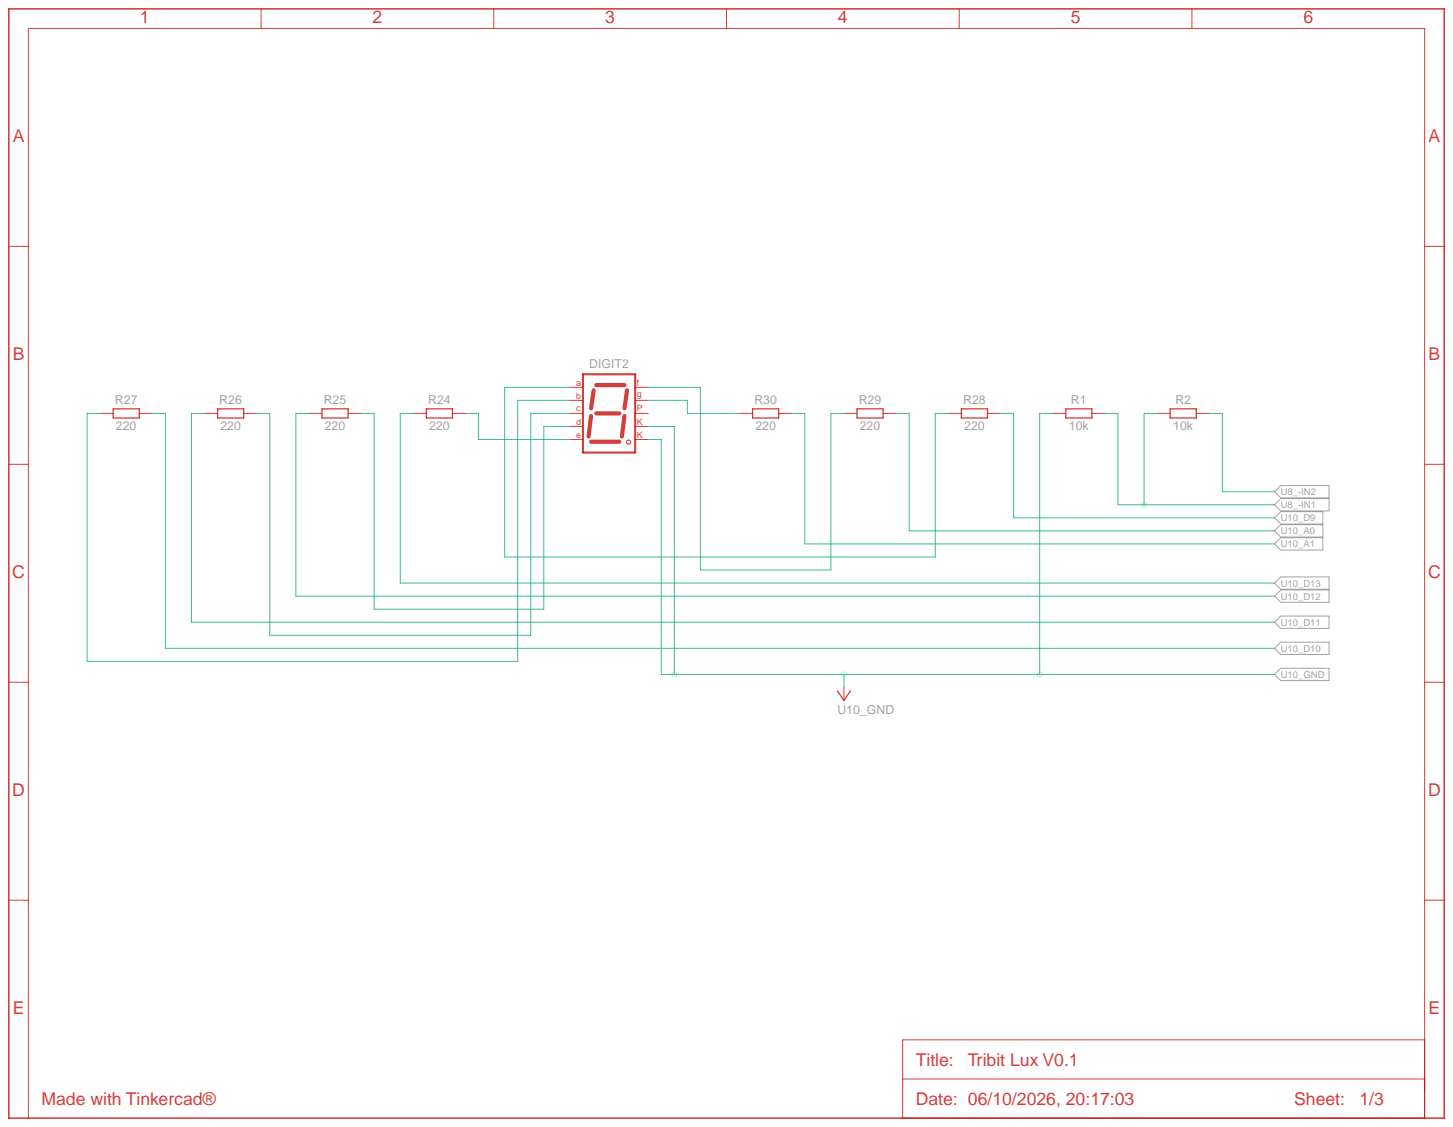
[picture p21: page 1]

A

1 | 2 | 3 | 4 | 5 | 6

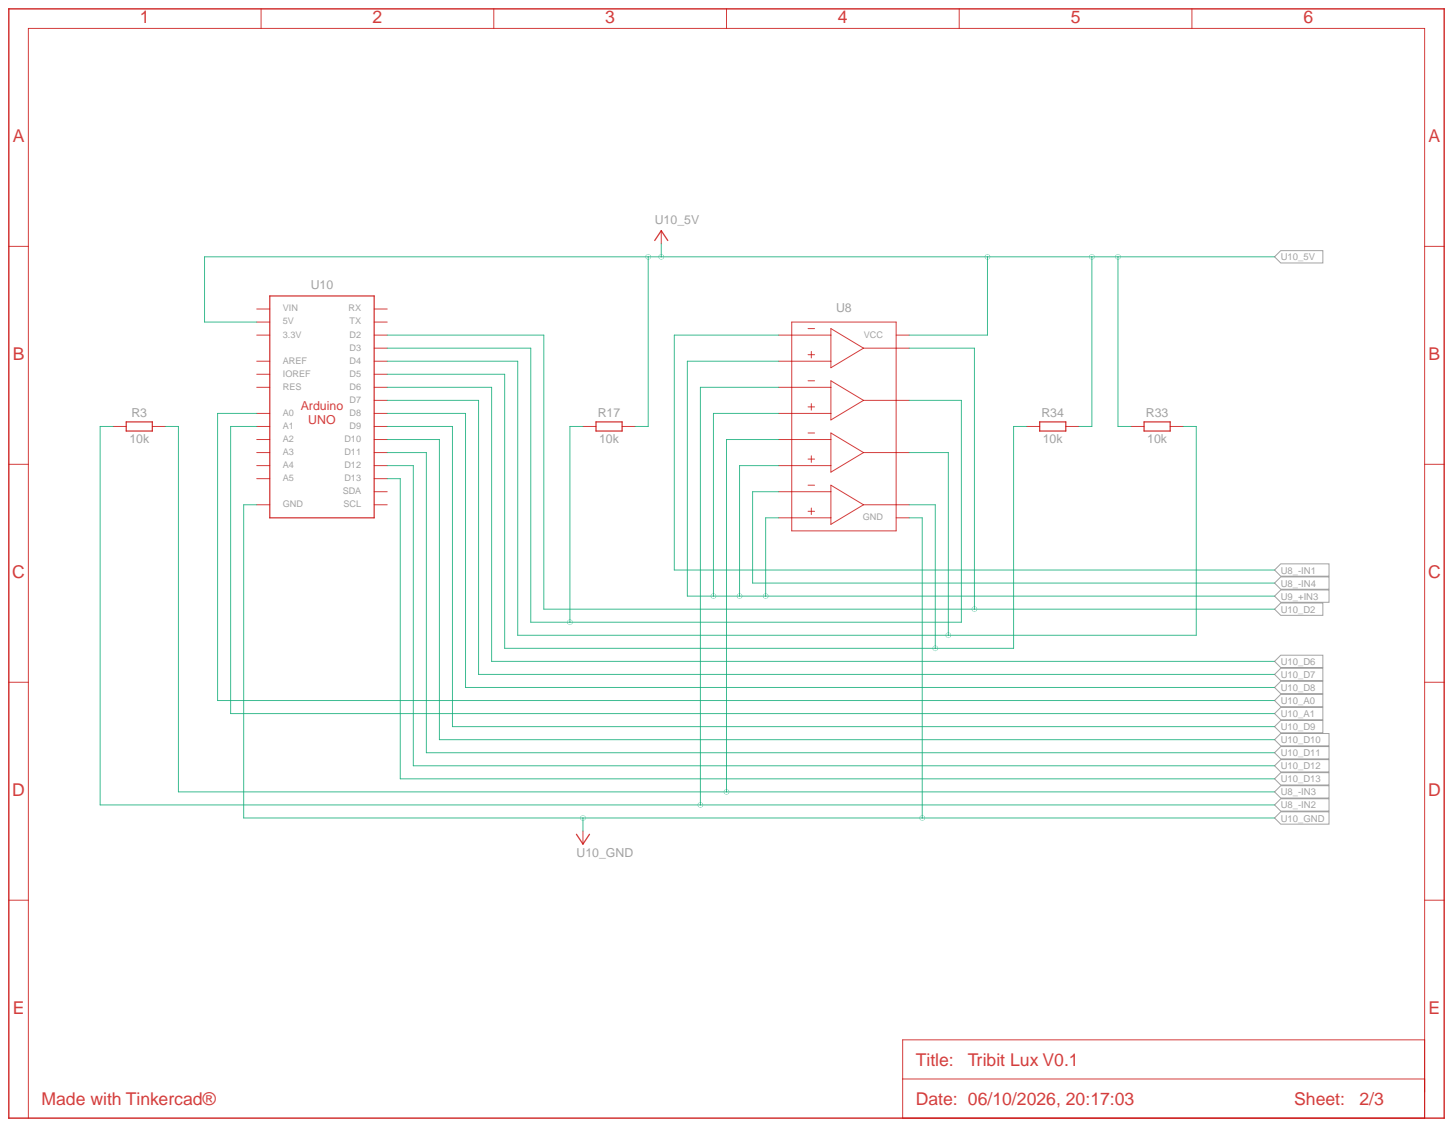
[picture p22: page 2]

A

1 | 2 | 3 | 4 | 5 | 6

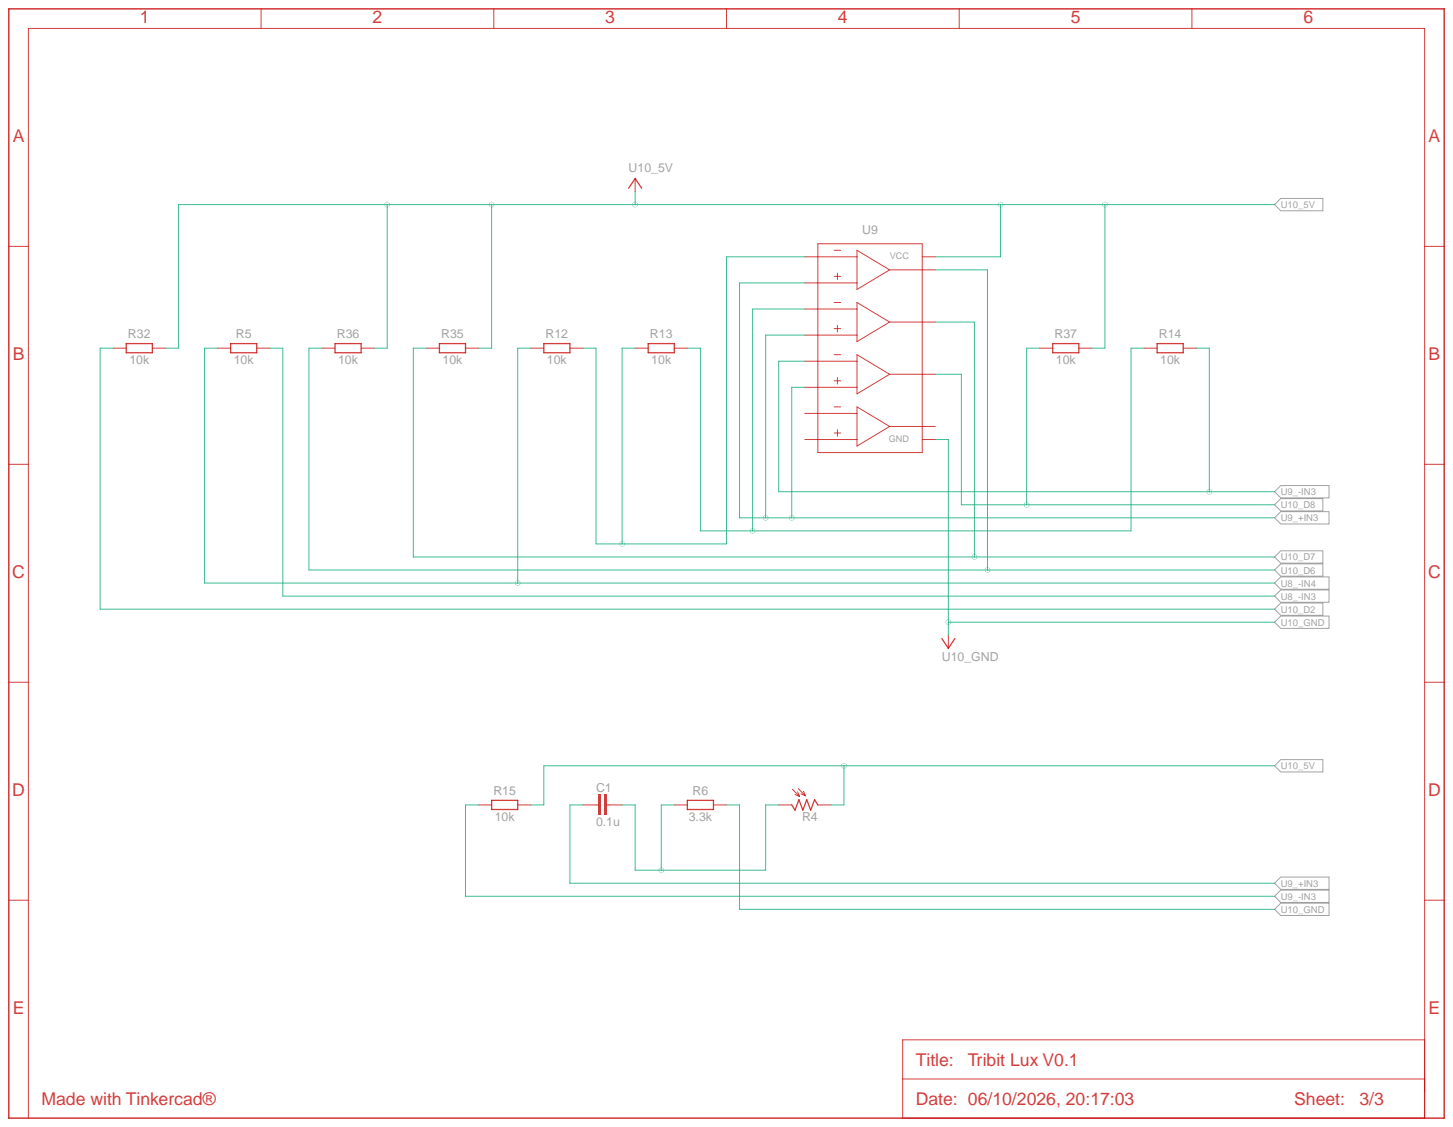
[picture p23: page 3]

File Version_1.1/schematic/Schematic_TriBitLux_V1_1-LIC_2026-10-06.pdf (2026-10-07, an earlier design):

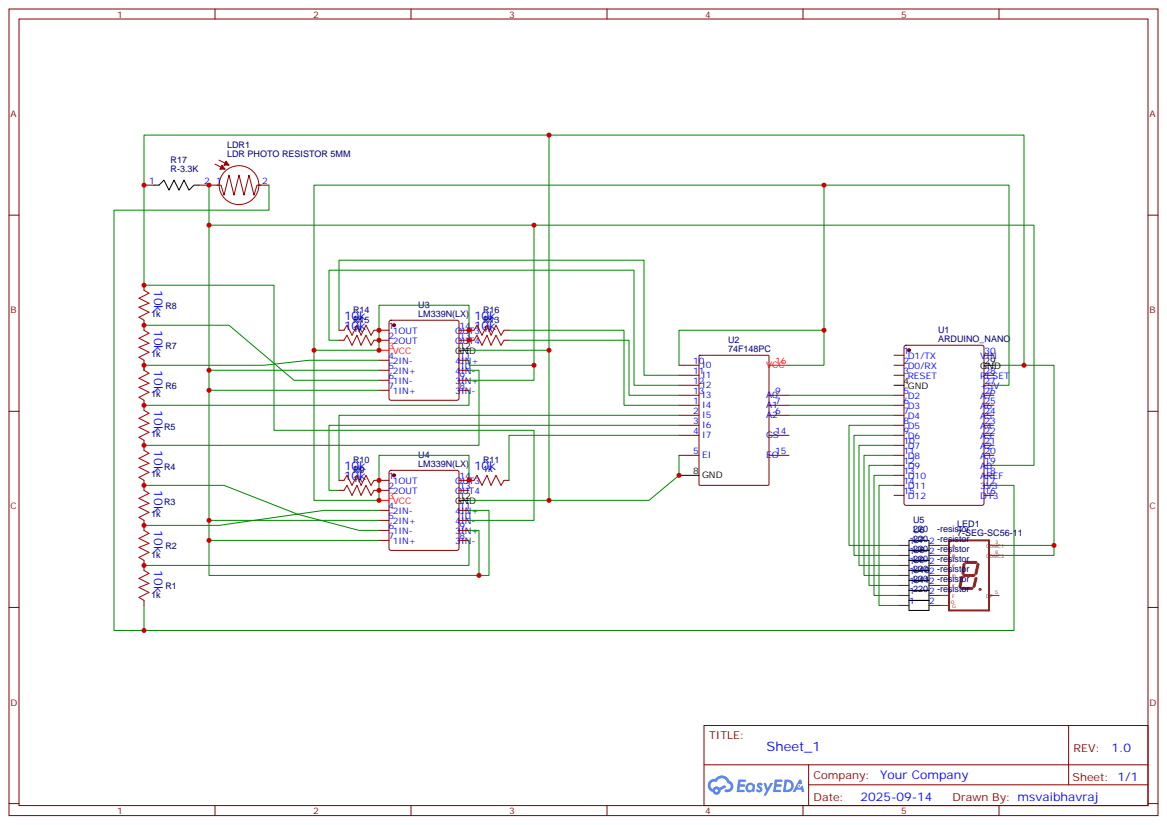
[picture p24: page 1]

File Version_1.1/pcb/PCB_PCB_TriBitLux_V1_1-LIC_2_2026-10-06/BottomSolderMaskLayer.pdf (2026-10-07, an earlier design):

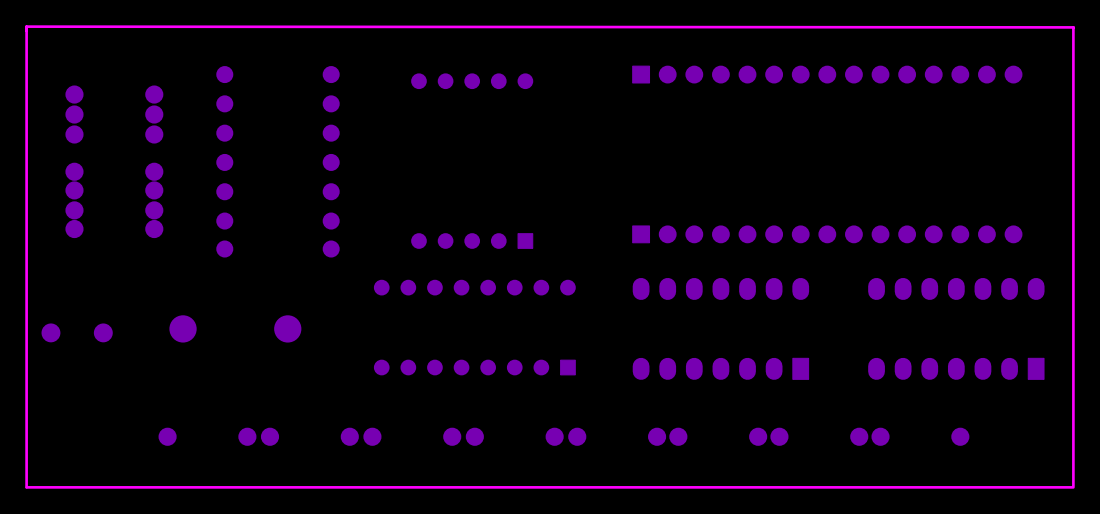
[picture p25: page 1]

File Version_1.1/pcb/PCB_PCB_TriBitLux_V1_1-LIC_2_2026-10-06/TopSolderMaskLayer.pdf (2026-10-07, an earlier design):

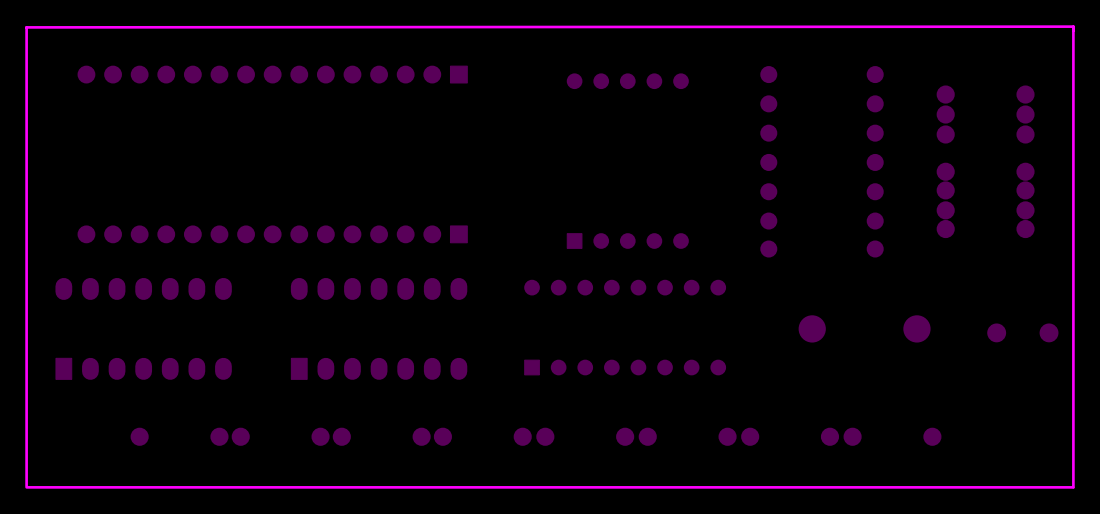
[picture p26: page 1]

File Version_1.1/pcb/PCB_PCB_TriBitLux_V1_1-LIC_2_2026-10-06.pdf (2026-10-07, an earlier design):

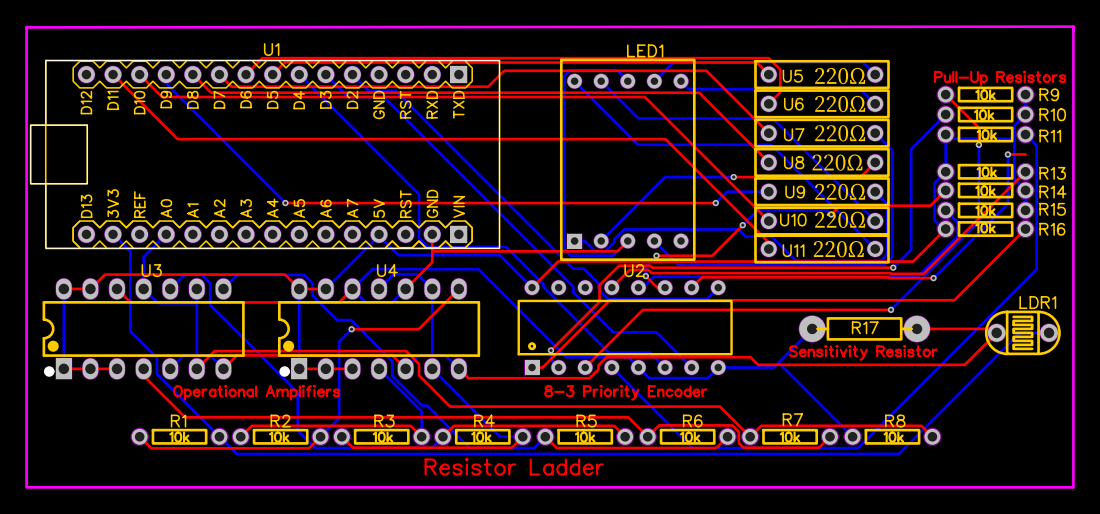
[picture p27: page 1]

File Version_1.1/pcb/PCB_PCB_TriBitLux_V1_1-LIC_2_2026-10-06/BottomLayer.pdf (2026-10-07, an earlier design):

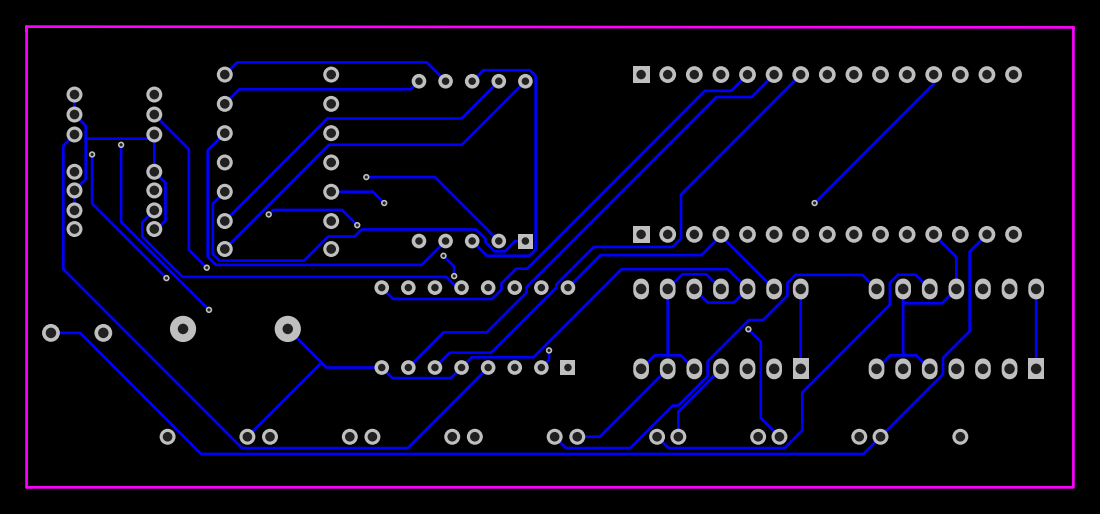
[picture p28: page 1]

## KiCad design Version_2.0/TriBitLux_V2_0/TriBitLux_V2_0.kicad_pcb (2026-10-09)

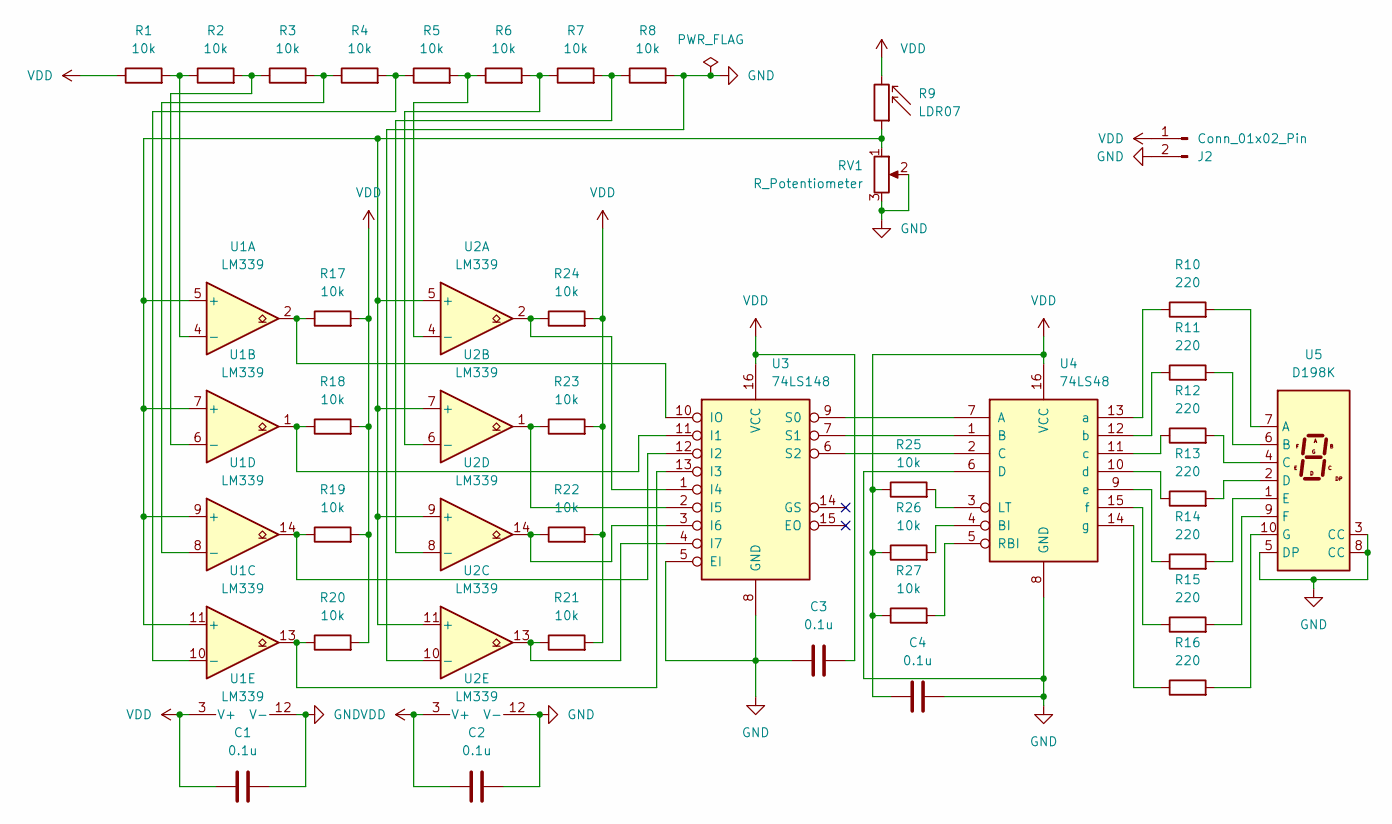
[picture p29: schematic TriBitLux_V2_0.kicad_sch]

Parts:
C1, C2, C3, C4: 0.1u; C_Disc_D10.0mm_W2.5mm_P5.00mm
J2: Conn_01x02_Pin; PinHeader_2x01_P2.54mm_Vertical
R1, R2, R3, R4, R5, R6, R7, R8, R17, R18, R19, R20, R21, R22, R23, R24, R25, R26, R27: 10k; R_Axial_DIN0207_L6.3mm_D2.5mm_P7.62mm_Horizontal
R9: LDR07; R_LDR_D20mm_P15.5mm_Vertical
R10, R11, R12, R13, R14, R15, R16: 220; R_Axial_DIN0207_L6.3mm_D2.5mm_P7.62mm_Horizontal
RV1: R_Potentiometer; Potentiometer_Runtron_RM-065_Vertical
U1, U2: LM339; DIP-14_W7.62mm
U3: 74LS148; DIP-16_W7.62mm
U4: 74LS48; DIP-16_W7.62mm
U5: D198K; 7SegmentLED_LTS6760_LTS6780

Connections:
GND: C1.2, C2.2, C3.2, C4.1, J2.2, R8.2, RV1.2, RV1.3, U1.12 (V-), U2.10 (-), U2.12 (V-), U3.5 (EI), U3.8 (GND), U4.6 (D), U4.8 (GND), U5.3 (CC), U5.5 (DP), U5.8 (CC)
unnamed: R9.1, RV1.1, U1.5 (+), U1.7 (+), U1.9 (+), U1.11 (+), U2.5 (+), U2.7 (+), U2.9 (+), U2.11 (+)
unnamed: R1.2, R2.1, U1.4 (-)
unnamed: R2.2, R3.1, U1.6 (-)
unnamed: R4.2, R5.1, U1.10 (-)
unnamed: R3.2, R4.1, U1.8 (-)
unnamed: R5.2, R6.1, U2.4 (-)
unnamed: R6.2, R7.1, U2.6 (-)
unnamed: R7.2, R8.1, U2.8 (-)
unnamed: R18.1, U1.1, U3.11 (I1)
unnamed: R19.1, U1.14, U3.12 (I2)
unnamed: R20.1, U1.13, U3.13 (I3)
unnamed: R24.1, U2.2, U3.1 (I4)
unnamed: R23.1, U2.1, U3.2 (I5)
unnamed: R22.1, U2.14, U3.3 (I6)
unnamed: R21.1, U2.13, U3.4 (I7)
unnamed: R17.1, U1.2, U3.10 (IO)
unnamed: U3.9 (S0), U4.7 (A)
unnamed: U3.7 (S1), U4.1 (B)
unnamed: U3.6 (S2), U4.2 (C)
unnamed: R26.2, U4.4 (BI)
unnamed: R25.2, U4.3 (LT)
unnamed: R27.2, U4.5 (RBI)
unnamed: R10.1, U4.13 (a)
unnamed: R11.1, U4.12 (b)
unnamed: R12.1, U4.11 (c)
unnamed: R13.1, U4.10 (d)
unnamed: R14.1, U4.9 (e)
unnamed: R15.1, U4.15 (f)
unnamed: R16.1, U4.14 (g)
unnamed: R10.2, U5.7 (A)
unnamed: R11.2, U5.6 (B)
unnamed: R12.2, U5.4 (C)
unnamed: R13.2, U5.2 (D)
unnamed: R14.2, U5.1 (E)
unnamed: R15.2, U5.9 (F)
unnamed: R16.2, U5.10 (G)
VDD: C1.1, C2.1, C3.1, C4.2, J2.1, R1.1, R9.2, R17.2, R18.2, R19.2, R20.2, R21.2, R22.2, R23.2, R24.2, R25.1, R26.1, R27.1, U1.3 (V+), U2.3 (V+), U3.16 (VCC), U4.16 (VCC)

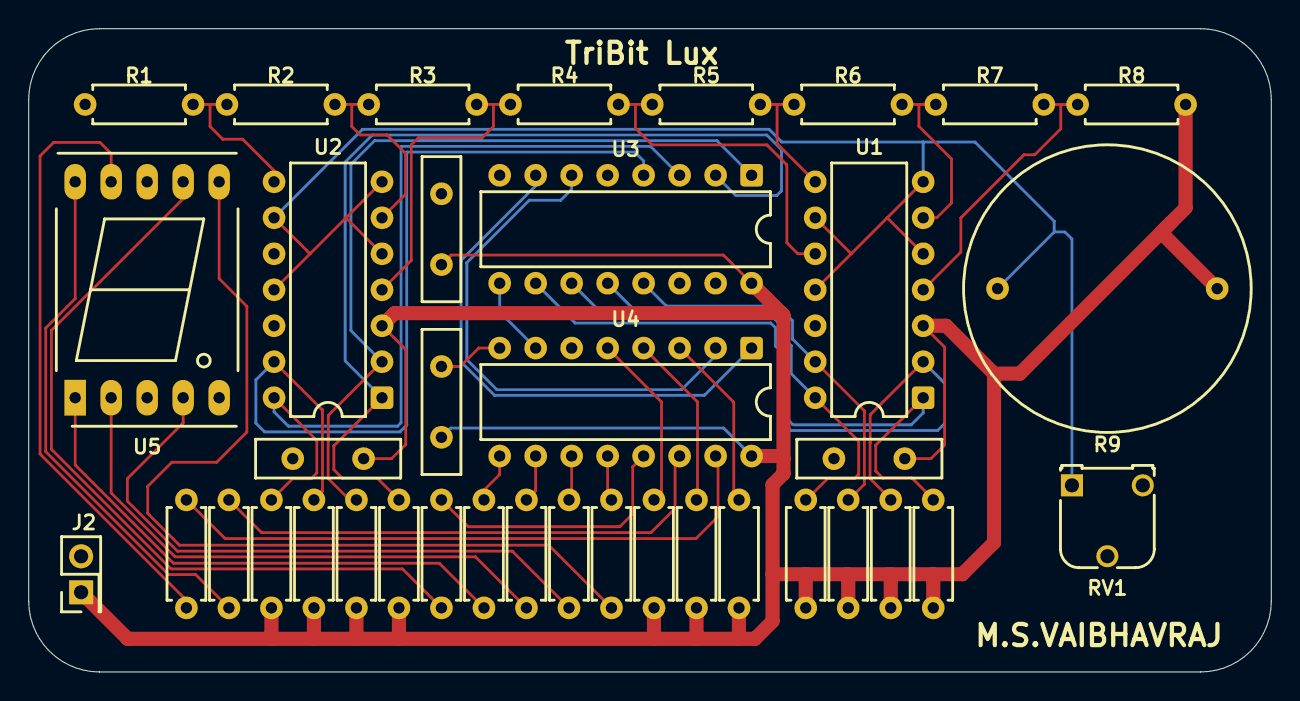
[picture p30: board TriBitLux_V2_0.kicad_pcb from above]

Board: 2 copper layers, 87.7 x 45.4 mm, 38 parts (0 on the bottom side), 38 nets.

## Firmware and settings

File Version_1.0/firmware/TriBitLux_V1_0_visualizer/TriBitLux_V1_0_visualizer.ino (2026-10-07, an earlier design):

// ================================================================
//  7-Segment Display Visualizer — Arduino Nano
//  Reads SN74LS48N (BCD→7seg decoder) outputs f,g,a,b,c,d,e
//  mapped to analog pins A6 → A0, then draws the active digit
//  in the Serial Monitor as ASCII art (like a real 7-seg display).
//
//  SN74LS48N Output Logic: ACTIVE HIGH (logic 1 = segment ON)
//  Display Type Driven:    Common Cathode
//
//  Pin Mapping:
//    Segment  Arduino Pin   Notes
//    -------  -----------   -----------------------------------
//      f      A6            ⚠ ANALOG-ONLY on Nano — uses analogRead()
//      g      A5            Digital-capable
//      a      A4            Digital-capable
//      b      A3            Digital-capable
//      c      A2            Digital-capable
//      d      A1            Digital-capable
//      e      A0            Digital-capable
//
//  7-Segment layout reference:
//        _
//       |_|     <- segments: a(top), f(top-left), g(mid), b(top-right)
//       |_|     <- segments: e(bot-left), d(bot), c(bot-right)
//
//  ASCII art output per frame (in Serial Monitor):
//        _
//       | |     (for digit '0')
//       |_|
// ================================================================

// --- Pin Definitions -----------------------------------------
// A6 and A7 on Arduino Nano are ANALOG-ONLY pins.
// They cannot be configured with pinMode() or read with digitalRead().
// Only analogRead() works on A6/A7.
#define PIN_F  A6   // Segment f -- top-left vertical   (ANALOG-ONLY)
#define PIN_G  A5   // Segment g -- middle horizontal
#define PIN_A  A4   // Segment a -- top horizontal
#define PIN_B  A3   // Segment b -- top-right vertical
#define PIN_C  A2   // Segment c -- bottom-right vertical
#define PIN_D  A1   // Segment d -- bottom horizontal
#define PIN_E  A0   // Segment e -- bottom-left vertical

// --- Threshold for Analog -> Logic conversion -----------------
// analogRead() returns 0-1023.
// VCC/2 = 2.5V -> ~512 counts.
// Any reading above this midpoint is treated as logic HIGH.
// Adjust lower (e.g. 400) if your 74LS48 HIGH level is weak.
#define ANALOG_THRESHOLD  512

// --- Display refresh rate ------------------------------------
// How often the Serial Monitor updates (milliseconds).
// 200ms = ~5 frames/sec. Lower = faster but more serial traffic.
#define REFRESH_MS  200

// ================================================================
//  Helper: readDig -- reads a standard digital-capable analog pin.
//  Returns true  if the pin is pulled HIGH by the 74LS48 output.
//  Returns false if the pin is LOW (segment OFF).
// ================================================================
bool readDig(uint8_t pin) {
  return digitalRead(pin) == HIGH;
}

// ================================================================
//  Helper: readAnlg -- reads A6 (analog-only pin) by comparing
//  its raw ADC count against the midpoint threshold.
//  Returns true  (HIGH) if ADC value > ANALOG_THRESHOLD.
//  Returns false (LOW)  otherwise.
// ================================================================
bool readAnlg(uint8_t pin) {
  return analogRead(pin) > ANALOG_THRESHOLD;
}

// ================================================================
//  Helper: segChar -- returns the display character for a segment.
//  seg      : boolean state of the segment (true = ON)
//  onChar   : character to print when segment is ON  (e.g. '_' or '|')
//  offChar  : character to print when segment is OFF (usually ' ')
// ================================================================
char segChar(bool seg, char onChar, char offChar) {
  return seg ? onChar : offChar;
}

// ================================================================
//  setup() -- runs once at power-on / reset
// ================================================================
void setup() {
  Serial.begin(9600);   // Open serial port at 9600 baud

  // Configure A0-A5 as INPUT.
  // No internal pull-up needed -- the SN74LS48N actively drives HIGH/LOW.
  // A6 is analog-only, so we intentionally skip it here.
  pinMode(PIN_G, INPUT);  // A5
  pinMode(PIN_A, INPUT);  // A4
  pinMode(PIN_B, INPUT);  // A3
  pinMode(PIN_C, INPUT);  // A2
  pinMode(PIN_D, INPUT);  // A1
  pinMode(PIN_E, INPUT);  // A0

  // Print a startup banner to Serial Monitor
  Serial.println(F("========================================"));
  Serial.println(F("  SN74LS48N -> 7-Seg ASCII Visualizer  "));
  Serial.println(F("  f->A6  g->A5  a->A4  b->A3            "));
  Serial.println(F("  c->A2  d->A1  e->A0                   "));
  Serial.println(F("========================================"));
  Serial.println();
}

// ================================================================
//  loop() -- runs continuously; reads pins and draws the display
// ================================================================
void loop() {

  // -- Step 1: Read all 7 segment lines -----------------------
  // Each variable is true (1) if the SN74LS48N is asserting that
  // segment HIGH (i.e., that segment should be lit).

  bool seg_a = readDig(PIN_A);   // Top horizontal bar
  bool seg_b = readDig(PIN_B);   // Top-right vertical bar
  bool seg_c = readDig(PIN_C);   // Bottom-right vertical bar
  bool seg_d = readDig(PIN_D);   // Bottom horizontal bar
  bool seg_e = readDig(PIN_E);   // Bottom-left vertical bar
  bool seg_f = readAnlg(PIN_F);  // Top-left vertical bar  (A6 analog-only)
  bool seg_g = readDig(PIN_G);   // Middle horizontal bar

  // -- Step 2: Build and print ASCII art ----------------------
  //
  // The 3-line ASCII layout maps to segments like this:
  //
  //   Line 1:  " _ "   ->  space, a, space
  //   Line 2:  "|_|"   ->  f,     g, b
  //   Line 3:  "|_|"   ->  e,     d, c
  //
  // segChar() selects the correct character based on segment state.

  Serial.println();  // Blank line to visually separate each frame

  // Line 1 -- Top segment (a)
  Serial.print(' ');
  Serial.print(segChar(seg_a, '_', ' '));   // '_' if a is ON, space if OFF
  Serial.println(' ');

  // Line 2 -- Upper body (f, g, b)
  Serial.print(segChar(seg_f, '|', ' '));   // '|' if f ON (top-left)
  Serial.print(segChar(seg_g, '_', ' '));   // '_' if g ON (middle)
  Serial.println(segChar(seg_b, '|', ' ')); // '|' if b ON (top-right)

  // Line 3 -- Lower body (e, d, c)
  Serial.print(segChar(seg_e, '|', ' '));   // '|' if e ON (bottom-left)
  Serial.print(segChar(seg_d, '_', ' '));   // '_' if d ON (bottom)
  Serial.println(segChar(seg_c, '|', ' ')); // '|' if c ON (bottom-right)

  // -- Step 3: Optional -- print segment states for debugging -
  // Uncomment the block below to see raw HIGH/LOW states per pin.
  /*
  Serial.print(F("  [a="));  Serial.print(seg_a);
  Serial.print(F(" b="));    Serial.print(seg_b);
  Serial.print(F(" c="));    Serial.print(seg_c);
  Serial.print(F(" d="));    Serial.print(seg_d);
  Serial.print(F(" e="));    Serial.print(seg_e);
  Serial.print(F(" f="));    Serial.print(seg_f);
  Serial.print(F(" g="));    Serial.print(seg_g);
  Serial.println(F("]"));
  */

  // -- Step 4: Wait before next frame -------------------------
  delay(REFRESH_MS);
}

// ================================================================
//  Expected ASCII output per BCD digit (SN74LS48N truth table):
//
//  Digit  a  b  c  d  e  f  g    ASCII
//  -----  -  -  -  -  -  -  -    -----
//    0    1  1  1  1  1  1  0     _
//                               | |
//                               |_|
//
//    1    0  1  1  0  0  0  0
//                                 |
//                                 |
//
//    2    1  1  0  1  1  0  1     _
//                                _|
//                               |_
//
//    3    1  1  1  1  0  0  1     _
//                                _|
//                                _|
//
//    4    0  1  1  0  0  1  1
//                               |_|
//                                 |
//
//    5    1  0  1  1  0  1  1     _
//                               |_
//                                _|
//
//    6    1  0  1  1  1  1  1     _
//                               |_
//                               |_|
//
//    7    1  1  1  0  0  0  0     _
//                                 |
//                                 |
//
//    8    1  1  1  1  1  1  1     _
//                               |_|
//                               |_|
//
//    9    1  1  1  1  0  1  1     _
//                               |_|
//                                _|
// ================================================================

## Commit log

2026-10-07 Refinement of Version 2.0
    [TriBitLux_V2_0.kicad_sch]
2026-10-07 Replace V1.1 schematic image with updated version
    Updated the schematic image in the README to the latest version.
2026-10-08 Reorganized the project structure to improve clarity and maintainability. Moved assets, firmware, schematics, and other relevant files into their respective directories for better organization. Remov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
    [BOM_TriBitLux_V1_1-LIC_2026-10-06.csv, TriBitLux_V2_0-BOM-JLCPCB.csv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]
2026-10-08 Modifications for Readme.md and .gitignore files, and added a new GIF asset for the TriBitLux 5V demo in dark mode.
2026-10-09 Input of the Comparator is reversed to make it work with active low priority encoder. The output of the comparator is now connected to the active low input of the priority encoder.
    [TriBitLux_V2_0.kicad_pcb, TriBitLux_V2_0.kicad_sch]
2026-10-18 Schematics Fix and Update: As the circuit was only counting from 1 to 7 and debugged it to count from 0 to 7, Reference voltage of LDR and Resistor was changed to 3.3V from 5V.
2026-10-30 Hybrid Design Version 2.1 of the TriBitLux PCB design, including updated schematic, layout, and assets.
2026-11-01 2.5V Part is Updated to TL431A TO-92 Body 4.1x3.1mm P1.27mm
2026-11-01 QR code's foot print for TriBitLux V2.1 Custom PCB.
2026-11-02 DIP IC Sockets are placed instead the IC itself, so that the IC can be replaced if it fails. The IC is placed in a socket, which is soldered to the PCB. This allows for easy replacement of the IC wit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
2026-11-03 JLCPCB Gerber files for TriBitLux V2.1
